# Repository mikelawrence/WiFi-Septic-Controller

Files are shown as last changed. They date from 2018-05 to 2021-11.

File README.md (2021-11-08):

# Wireless Septic Controller
I had some problems with my newly installed aerobic septic system when hurricane Harvey blew through. There was no significant flooding but there was plenty of rain and that seemed to cause the system to override pump multiple times. This board is designed to give visibility as to how often the pump runs and will detail alarm conditions. The effluent pump is controlled with an external 50A Solid-State-Relay (SSR). This board also provides an alarm output required by most aerobic septic systems. Normally the alarm switches are wired in parallel so that any alarm condition will turn on the light and audible alert. This board has separate inputs for three alarm switches so that the alarm condition can be identified. This board supports the following alarm types: air pressure failure alarm, tank high level alarm, and bleach low level alarm. WiFi is provided by an ATWINC1500 module which is an excellent low power WiFi module that is directly supported by Arduino. This board is fully compatible with the Arduino MRK1000 which includes a SAMD21G18 ARM processor and a ATWINC1500 module. This board uses MQTT to communicate with Home Assistant home automation software. The MQTT client/server model is very effective in this situation.

This PCB design uses my custom libraries available here [Mike's KiCad Libraries](https://github.com/mikelawrence/KiCad-Libraries).

This PCB was designed with [KiCad 5.1.2](http://kicad.org).

_Note: There is dangerous voltage present on this PCB. Use care when handling this board. Housing this board in a box is required to protect users from electrocution._

_Note: The LMZ21700 Simple Switcher, SAMD21G18 ARM Processor, and ATWINC1500 WiFi Module have exposed pads on the bottom which requires either a reflow oven or hot air to solder properly._

For Bill of Materials generation I use my version of [KiBoM](https://github.com/mikelawrence/KiBoM) forked from [SchrodingersGat](https://github.com/SchrodingersGat/KiBoM).

## Status
* Rev 1.1 PCB has been updated to support KiCad 5.1 libraries. Some footprints changed when libraries were updated but changes were minimal. This board has NOT been tested.
  * Order the PCB from [OSH Park](https://oshpark.com/shared_projects/a805S6zq).
  * Order the parts from Mouser using this [Shared BOM](https://www.mouser.com/ProjectManager/ProjectDetail.aspx?AccessID=a71ed4612f).
* Rev 1.0 PCB has been ordered, assembled, and tested. Hardware is fully operational.
  * Order the PCB from [OSH Park](https://oshpark.com/shared_projects/bguWSc9J).
  * Order the parts from Mouser using this [Shared BOM](https://www.mouser.com/ProjectManager/ProjectDetail.aspx?AccessID=a71ed4612f).

## Board Preview
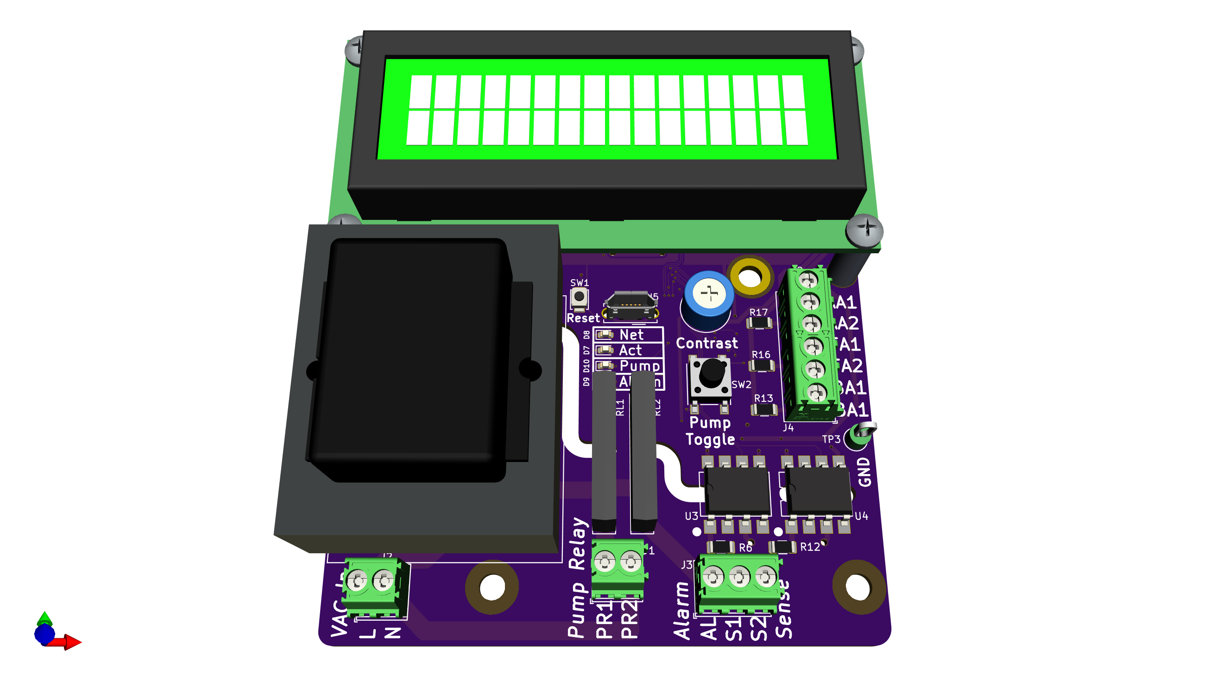
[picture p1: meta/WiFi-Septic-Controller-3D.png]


## Design
### Input Power
A transformer converts the 115VAC to 10VAC through a standard bridge rectifier and capacitor filter to arrive at approximately 12VDC. This voltage is fed to both a 3.3VDC and 5VDC Simpler Switcher from Texas Instruments (LMZ21700). The switchers can also be fed by the 5VDC from the USB connector when the 115VAC is not connected. But make note, the 5VDC is no longer regulated.

### Alarm Contact Inputs
There are three alarm contact inputs: air pressure failure alarm, tank high level alarm, and bleach low level alarm. Aerobic septic systems have an air compressor that pumps air into the septic tank, hence the name "aerobic". This air pump promotes bacterial growth and it runs all the time. If the air pump stops producing air pressure the air pressure failure alarm contact closes. Many aerobic septic systems use liquid bleach for the chlorine source and some regulatory boards require a low bleach level alarm. My aerobic septic system has three float switches but only one is the tank high level alarm. This float switch is at the highest point in the tank and this alarm means the pump cannot keep up with the water entering the tank. This is usually caused by the effluent pump failing.

In the previous wiring of the septic controller the alarm contacts were wired in parallel logically "or'ing" the alarms. The contacts switched 115VAC to the alarm light and audible alert. In order to determine the actual alarm state the wiring was changed to directly connect these contacts to the the board and they no longer switch 115VAC. The alarm contact inputs use a simple pullup to 5VDC and a Schmidt Trigger Inverter (SN74LVC2G14). Note: software debounce is still required. A high value pullup resistor and series resistor (both 100k) were selected to reduce current levels when accidental high voltages are applied to the input. ESD Protection devices are included to further protect the inputs. Due the inverted nature of the SN74LVC2G14 the software sees a logic high when the contact is closed.

### Sense Inputs
There are two 115VAC sense inputs (S1 and S2). These inputs are connected to an On Semiconductor MID400 AC Line Monitor. This optically-isolated device provides a logic low when 115VAC is present on the input. There is no flickering due to 60Hz AC. S1 is used to sense when the effluent pump has power. These is needed because the effluent pump can be turned on when the override float is tripped. S2 is currently unused.

### Relay Outputs
There are two relay outputs on the PR and ALM. Both are switched 115VAC by small board mount solid state relays  (). These SSRs provide overload protection for both temperature and current. The Pump Relay (PR) output is connected to the effluent pump 50A solid state relay (Crydom CWA2450-10). A 50A relay is needed to drive the 3/4hp effluent pump. Note this relay is controlled by 115VAC. The other relay output (AL) is the alarm output. The alarm light and audible alert require 10W at 115VAC. The alarm output is switched on when any alarm contact is closed. There is no software intervention required to produce an alarm.

### SAMD ARM Processor and WiFi Module
The ARM processor and ATWINC1500 WiFi module are wired identical to the MKR1000 Arduino board, thus the Arduino development environment is used for software development and the ATWINC1500 module is directly supported. Digital power is 3.3V and while the LCD is 5V there are no 5V outputs driving 3.3V inputs on the ARM processor so there is no problem wiring the LCD directly to the ARM processor. The LCD recognizes anything above 2.2VDC as a high so 3.3VDC logic outputs from ARM processor will be correctly interpreted by the LCD.

## Setup
### Arduino Setup
This board is designed to mimic a [MKR1000](https://store.arduino.cc/usa/arduino-mkr1000) board from Arduino. Make sure the the MKR1000 board is supported by installing Arduino SAMD Boards package. Do this by opening the Board Manager as shown below.

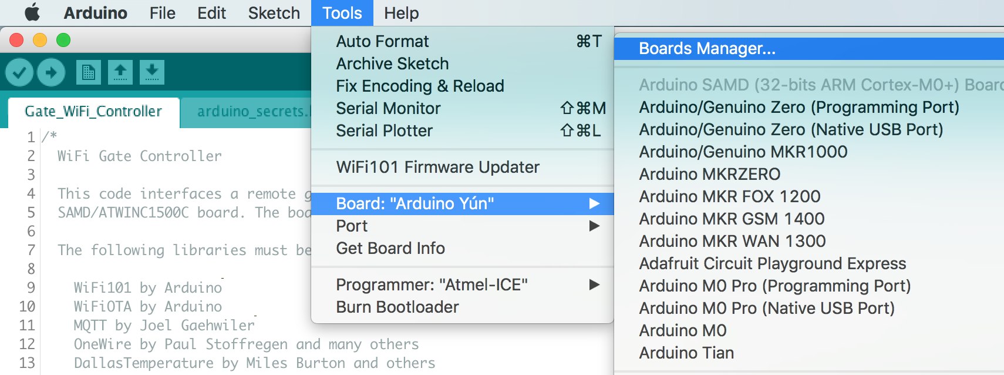
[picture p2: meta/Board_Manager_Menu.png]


Type in "samd" in the filter edit and you will see several options. Select "Arduino SAMD Boards (32-bits ARM Cortex-M0+)" and install the latest version as shown below.

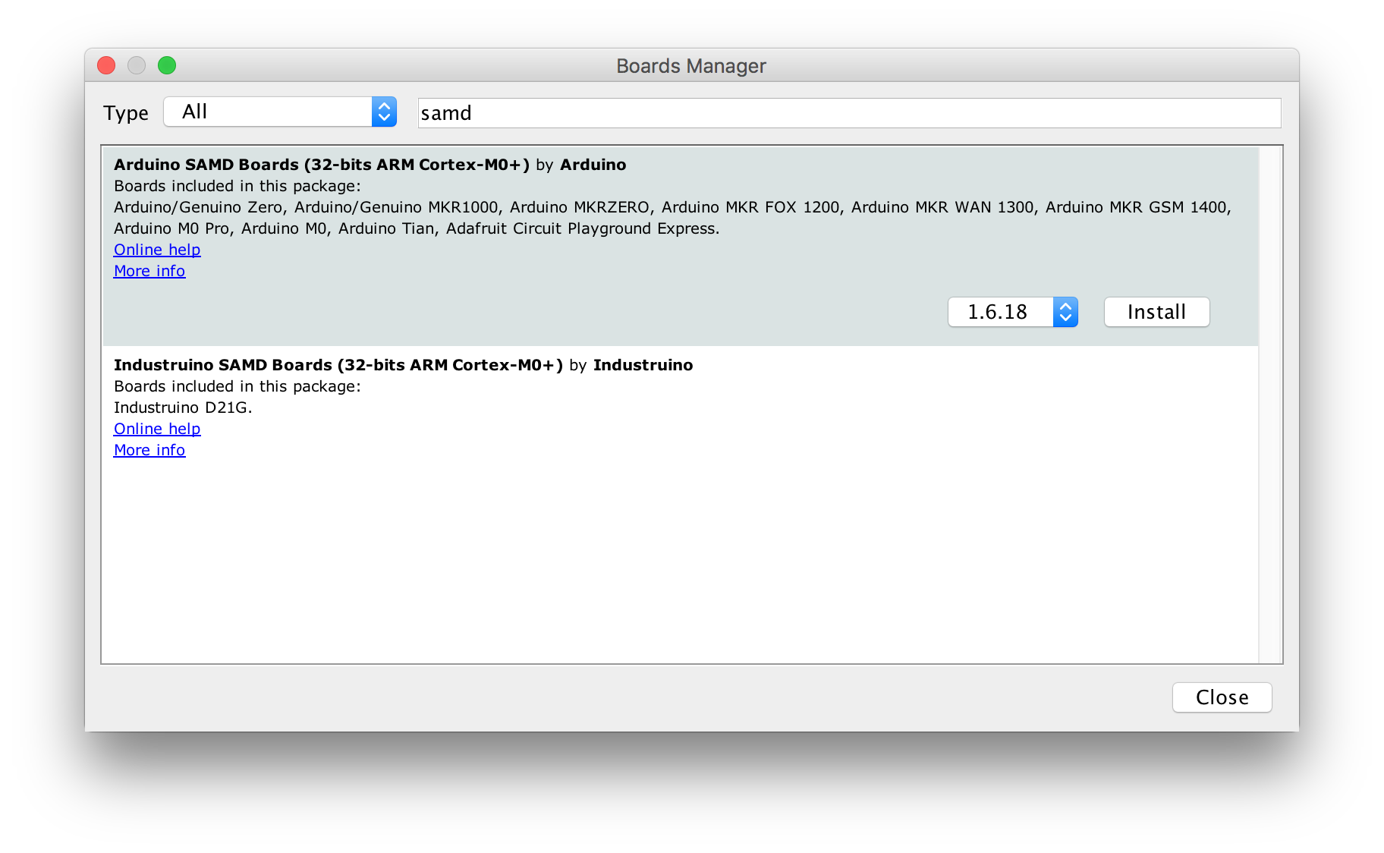
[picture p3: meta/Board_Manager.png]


It will take a few minutes to download and install the board package. Once complete it's time to install the necessary libraries. Start by opening the Library Manager as shown below.

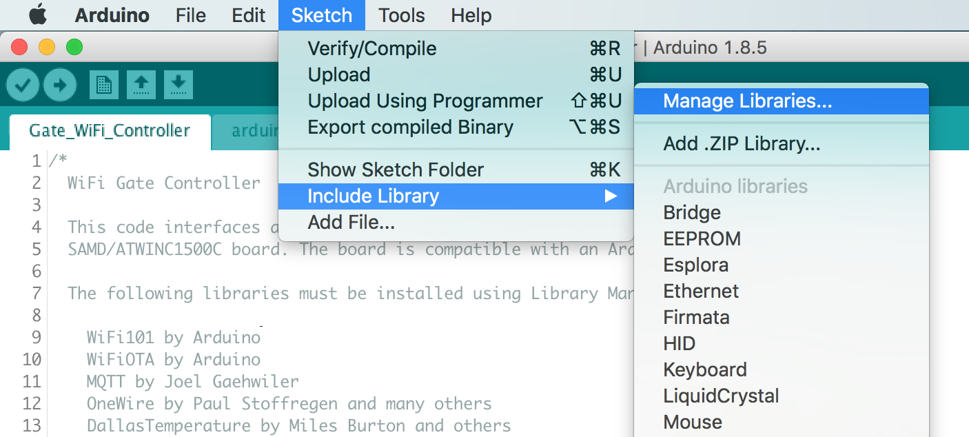
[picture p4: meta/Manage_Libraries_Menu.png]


Type in "mqtt" in the filter edit and scroll down until you see "MQTT by Joel Gaehwiler" as shown below.

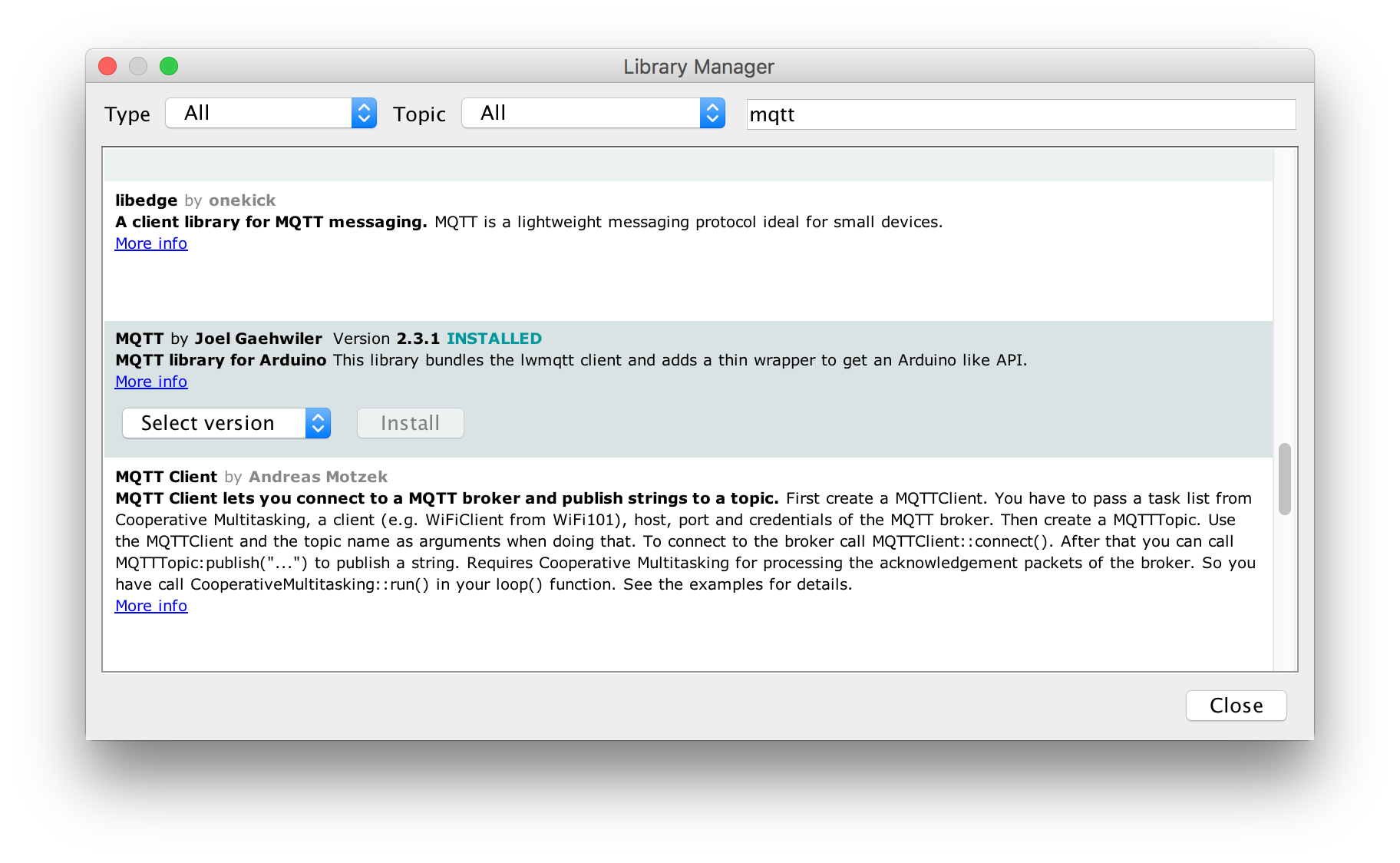
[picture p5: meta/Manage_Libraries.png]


Once "MQTT" is installed repeat the install for the following libraries.

* WiFi101 by Arduino
* WiFiOTA by Arduino
* OneWire by Paul Stoffregen and many others
* DallasTemperature by Miles Burton and others

### Board Setup
The Arduino development environment expects a bootloader in the SAMD ARM processor which will allow programming via USB. The bootloader must be programmed first using a supported programming pod. I used an "Atmel-ICE" pod but there are other options. First make sure you have selected the "Arduino/Genuino MKR1000" board as shown below.

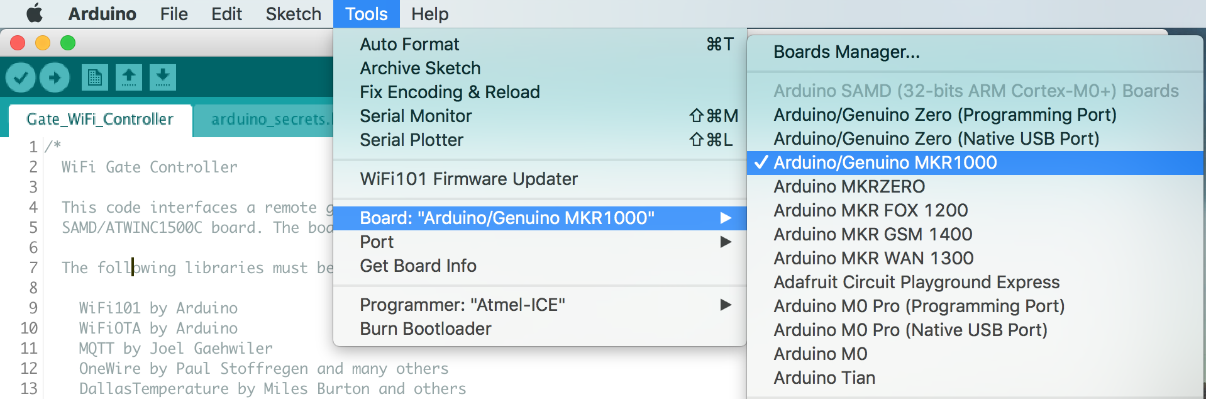
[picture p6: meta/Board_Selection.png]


Next select your programmer.

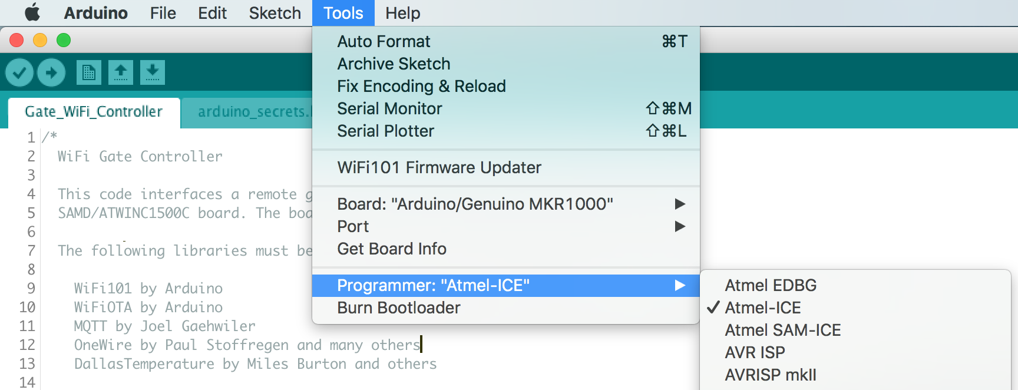
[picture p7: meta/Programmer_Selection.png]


Make sure the board is powered via USB and the programmer is connected to the debug connector then select "Burn Bootloader".

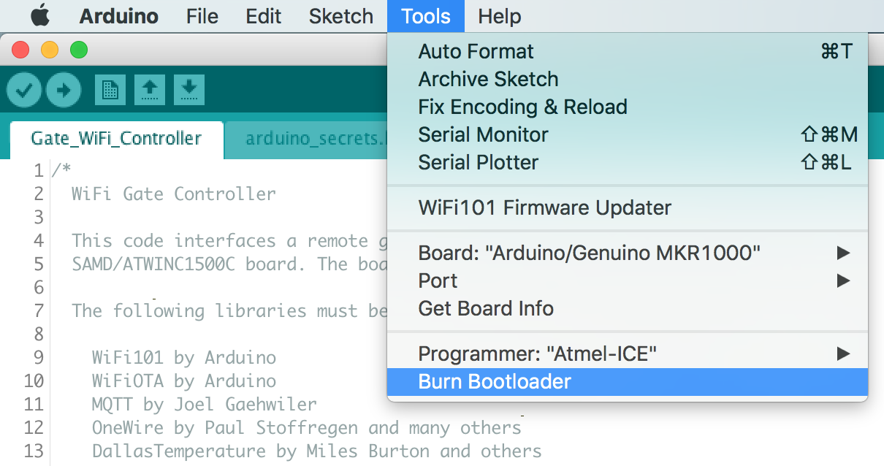
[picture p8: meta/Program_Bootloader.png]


Now the bootloader is programmed it's time to load the "WiFi101 FirmwareUpdater" example. This will update the firmware in the ATWINC1500 module.

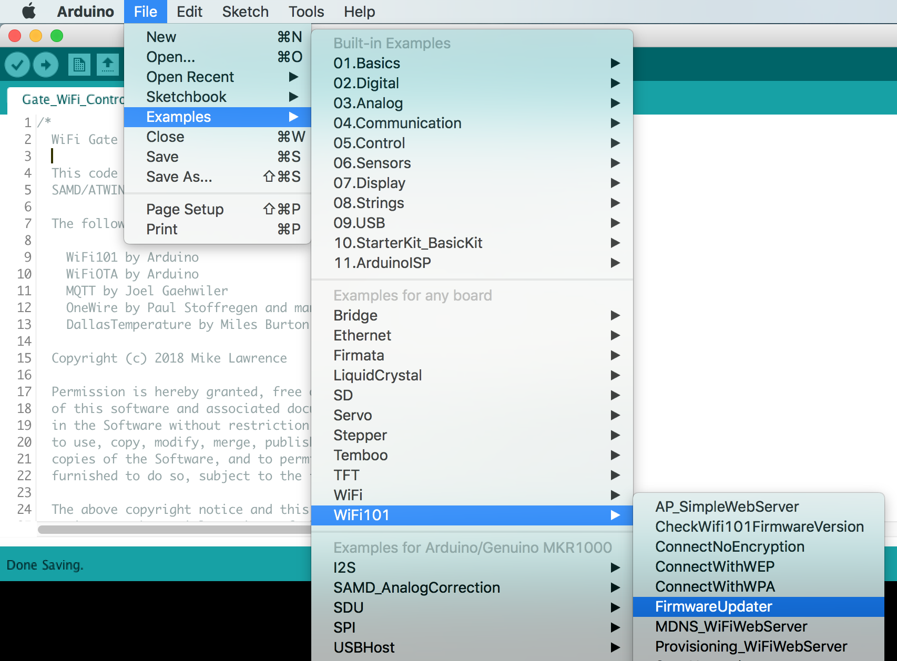
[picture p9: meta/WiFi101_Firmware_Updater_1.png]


Now "Upload" the "WiFi101 FirmwareUpdater" example.

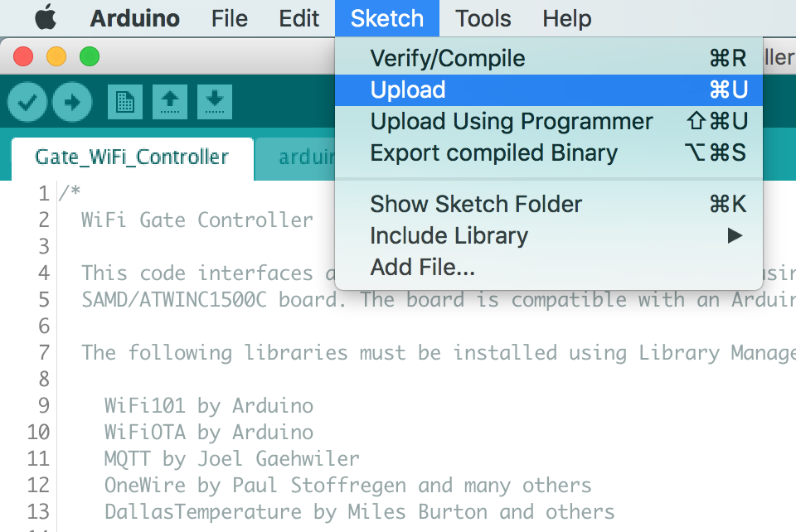
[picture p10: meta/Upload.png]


Update the ATWINC1500 module by selecting "WiFi101 Firmware Updater".

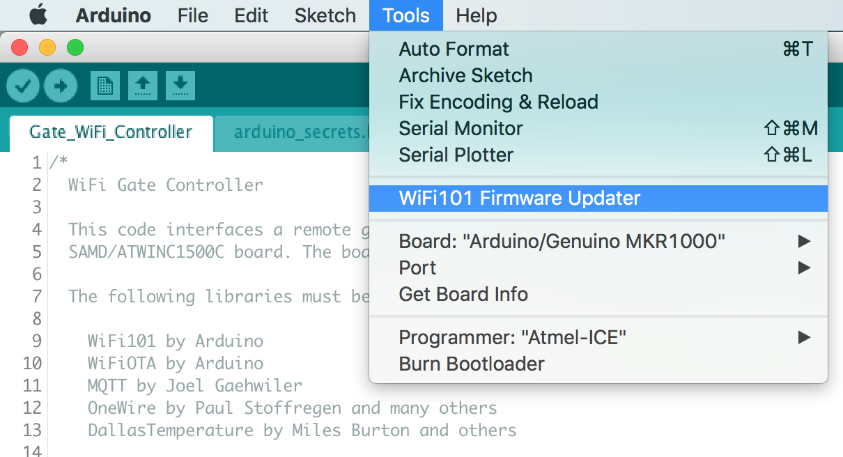
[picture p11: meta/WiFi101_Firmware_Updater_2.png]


Click the "Update Firmware" button.

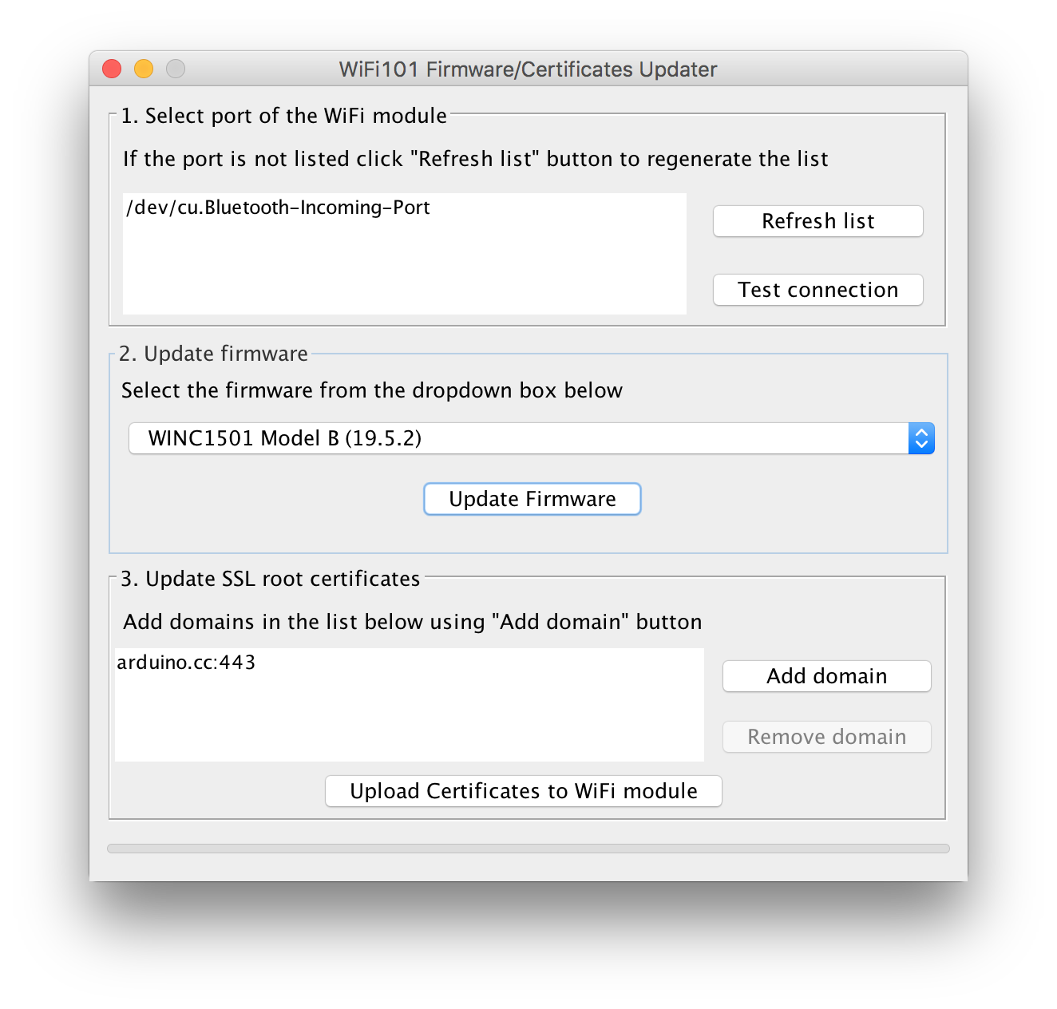
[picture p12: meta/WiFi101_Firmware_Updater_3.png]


Finally open the "Septic_WiFi_Controller.ino" sketch downloaded from GitHub. Update the necessary defines for your Wireless network and MQTT server settings see the [Code README](code/README.md) for more information. Now upload it just like the "WiFi101 FirmwareUpdater" example. All done!

# Acknowledgments
[Arduino](www.arduino.cc) kindly develops open source hardware and software which makes writing software for the board incredibly easy.

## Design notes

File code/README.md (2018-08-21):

# WiFi Septic Controller Sketch
The WiFi Septic Controller Sketch is written in C++. The sketch is primarily two state machines: one for effluent pump control and one for alarm state. The pump state machine can detect when the override float has applied power to the pump thus providing some indication of over usage or rain seepage into the tanks. The sketch is a discoverable set of sensors for [Home Assistant](https://home-assistant.io/), an open-source home automation platform running on Python. [MQTT](http://mqtt.org/), a machine-to-machine (M2M)/"Internet of Things" connectivity protocol, is the basis of communication with Home Assistant.

## Status
This software is in the testing stage and is connected to my septic system.
* This is now fixed. Automatic On at 1:00 AM is working but the time it comes has varied upwards of 15 minutes. Discovered that the WINC1500 module time keeping is pretty bad so it was bypassed with direct NTP handling in the WiFiRTC module.
* This is now fixed. Using WiFi Low Power mode may have contributed to the problem. Experienced the controller going silent on the network (pump state machine continues to work correctly). It appears that the WiFi module can loose connection and still show the status as connected. Added MQTT connect timeout which stops the WiFi connection. This stop causes the WiFi reconnect and hopefully fix the problem automatically. Also turned off WiFi Low Power Mode.
* Pump state machine is working nicely. Have tested Tank Empty, Off states, Manual On, Automatic On and Override On states. Overtemp state has not been tested.
* All alarms work correctly: Tank High Alarm, Air Pump Alarm, and Bleach Alarm. Overtemp Alarm has not been tested.
* Home Assistant detects all MQTT sensors: Status Sensor, Pump Sensor, Alarm Sensor, Temperature Sensor, and RSSI Sensor.

# Setup
## Sketch Setup
The arduino_secrets.h file is not included on Github. You must create and edit it to match your configuration.

```c
/******************************************************************
 * arduino_secrets.h
 ******************************************************************/
#define SECRET_SSID             "SSID of your WiFi network"
#define SECRET_PASSWORD         "Password for your WIFi network"
// IP address of MQTT server, host name should work but I've never tried
#define MQTT_SERVER             "192.168.0.230"
#define MQTT_SERVERPORT         1883
// MQTT user name and password leave as empty string if not used
#define MQTT_USERNAME           ""
#define MQTT_PASSWORD           ""
// Over-The-Air Update password if used
#define OTA_PASSWORD            "password"
```

The rest of the sketch settings are C defines in the [WiFi_Septic_Controller.h](WiFi Septic_Controller/WiFi_Septic_Controller.h) file. There are a few build defines that control how the sketch is built.

```c
/******************************************************************
 * Build defines
 ******************************************************************/
// Enable Watchdog Timer
#define ENABLE_WATCHDOG
// Enable OTA updates
#define ENABLE_OTA_UPDATES
// Enable Serial on USB
//#define ENABLE_SERIAL
// Enable Low Power Mode on WiFi
#define ENABLE_WIFI_LOW_POWER
// Current Version
#define VERSION                   "0.1"
```

* "ENABLE_WATCHDOG" - When defined, the Watchdog Timer is enabled with a 16 second timeout. This will reset the ARM processor is something goes bad.
* "ENABLE_OTA_UPDATES" - When defined, the sketch can be updated using Arduino's Over-The-Air Update capability.
* "ENABLE_SERIAL" - When defined, status information is sent out the serial connection which in this case is the USB port. Otherwise the serial port won't even be enabled.
* When "ENABLE_WIFI_LOW_POWER" is defined the WINC1500 module is set to Low Power Mode. This can drop the current requirements of the module to a third or even less. Low Power Mode reduces the transmit frequency to the beacon interval and may also cause the module to hang occasionally.

```c
/******************************************************************
 * Application defines
 ******************************************************************/
// Name of this board, each board should be unique
// Used as MQTT Client ID, HASS Name, and OTA Name
#define BOARD_NAME                "Septic"
// input debounce time in milliseconds
#define DEBOUNCE_TIME             100
// pump toggle switch input debounce time in milliseconds
//   Should be larger than DEBOUNCE_TIME
#define PUMP_TOGGLE_DEBOUNCE_TIME 500
// pump toggle switch input debounce time in milliseconds
//   Should be larger than DEBOUNCE_TIME
#define ALARM_DEBOUNCE_TIME       500
// pump state machine deadband time in milliseconds
#define PUMP_DEADBAND_TIME        2000
// alarm state machine deadband time in milliseconds
#define ALARM_DEADBAND_TIME       2000
// temperature publish time in milliseconds when pump is off
#define TEMP_PUBLISH_RATE         5 * 60 * 1000
// NTP server used to update local time, can be IP Address or name
#define NTP_SERVER                "time.nist.gov"
// timezone difference from GMT in hours (Standard Time difference)
#define TZDIFF                    -6
// Solid State Relay shutoff temperature in Celsius
#define SSR_SHUTOFF_TEMP          65.0

/******************************************************************
 * Home Assistant MQTT Defines
 ******************************************************************/
#define HASS_PREFIX               "hass"
#define HASS_NODE_NAME            "septic"
```
* "BOARD_NAME" - Names the board. It is used is several places including Home Assistant Name, OTA Name, and MQTT Client ID. This is a string.
* "DEBOUNCE_TIME" - How long to ignore sense changes on the input before accepting them as valid. This is an integer and the units are milliseconds.
* "PUMP_TOGGLE_DEBOUNCE_TIME" - How long to ignore contact changes on Pump Toggle switch. This is an integer and the units are milliseconds.
* "ALARM_DEBOUNCE_TIME" - How long to ignore contact changes on Alarm switch inputs. This is an integer and the units are milliseconds. Should be significantly larger than DEBOUNCE_TIME.
* "PUMP_DEADBAND_TIME" - How long after the Pump State Machine changes states before allowing another state change. This is an integer and the units are milliseconds.
* "ALARM_DEADBAND_TIME" - How long after the Alarm State Machine changes states before allowing another state change. This is an integer and the units are milliseconds.
* "TEMP_PUBLISH_RATE" - How often the temperature should be sampled and published via MQTT. This is an integer and the units are milliseconds. The time should not be less than 5000 milliseconds.
* "NTP_SERVER" - NTP Server that is used to update local time. NTP Updates occur slightly less than every 12 hours. This is a string and can be a valid DNS host name or IP Address.
* "TZDIFF" - Used to correct internet time for your given timezone. This should be the Standard Time timezone difference to GMT. It is a integer and units are hours.
* "SSR_SHUTOFF_TEMP" - Specifies the temperature is which the pump state machine will shut off the SSR. It is a float.
* "HASS_PREFIX" - The Home Assistant MQTT Discovery Prefix as defined in your system. This is a string.
* "HASS_NODE_NAME" - Used in the MQTT topics to identify the cover and sensor to Home Assistant. Home Assistant calls this the node id. It is a string and should not contain special characters including spaces.

## Home Assistant Setup
The sketch is setup to enable MQTT Discovery on Home Assistant. If you don't want to use discovery here is the configuration of the WiFi Septic Controller in Home Assistant. Note the 'Septic' in the name: definitions you see in the example yaml is the "BOARD_NAME" and 'septic' in topics is "HASS_NODE_NAME". The WiFi Septic Controller uses the [MQTT Sensor](https://home-assistant.io/components/sensor.mqtt/) and [MQTT Binary Sensor](https://www.home-assistant.io/components/binary_sensor.mqtt/) platforms.

```yaml
# Example configuration.yaml entry
sensor:
  # Septic Controller State
  - platform: mqtt
    name: "Septic Status"
    state_topic: "hass/sensor/septic/status/state"
  # Septic Controller Pump State
  - platform: mqtt
    name: "Septic Pump State"
    state_topic: "hass/binary_sensor/septic/pump/state"
  # Septic Controller Alarm State
  - platform: mqtt
    name: "Septic Alarm State"
    state_topic: "hass/binary_sensor/septic/alarm/state"
  # Septic Controller temperature
  - platform: mqtt
    name: "Septic Temperature"
    state_topic: "hass/sensor/septic/temperature/state"
    unit_of_measurement: "°C"
  # Septic Controller RSSI
  - platform: mqtt
    name: "Septic RSSI"
    state_topic: "hass/sensor/septic/rssi/state"
    unit_of_measurement: "dBm"
```

Septic Status can be one of the following:
* "Overtemp Alarm On" - The SSR temperature is too high and the effluent pump has been turned off. The pump will come back on when the temperature has dropped 15 C. Most likely the effluent pump is drawing too much current or the SSR is failing.
* "Tank High Alarm On" - The top float in the tank is on. Most likely the effluent pump is not working.
* "Air Pump Alarm On" - The air compressor is not producing any air pressure.
* "Bleach Alarm On" -  Bleach level is low.
* "Manual Pump On" - Effluent pump was manually turned on.
* "Auto Pump On" - Effluent pump was automatically turned on at 1:00AM.
* "Override Pump On" - The middle/override float is on which also turned on the effluent pump. This usually means too much water has entered the septic system.
* "Tank Empty" - This a short state that appears for a few seconds after pumping indicating the bottom float is off thus stopping any pumping state.
* "Idle" - Nothing to do except look pretty.

Once the board is running Home Assistant should automatically pick up the cover and sensors with MQTT Discovery. Debugging Home Assistant problems is a bit of a stretch for this guide but here are a couple of hints.

* Make sure you have MQTT installed. If you use HASS.IO goto the HASS.IO configuration and install the Mosquitto Broker.
* Make sure you have MQTT discovery enabled. See [MQTT Discovery](https://home-assistant.io/docs/mqtt/discovery/).
* Make sure your MQTT discovery prefix matches the HASS_PREFIX in the [WiFi_Septic_Controller.h](WiFi Septic_Controller/WiFi_Septic_Controller.h) file.

I use HASS.IO with the Mosquitto Broker add-on installed and my configuration for MQTT is as follows...

```yaml
mqtt:
  broker: core-mosquitto
  discovery: true
  discovery_prefix: hass

```

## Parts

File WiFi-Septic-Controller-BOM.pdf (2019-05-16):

Quantity | References | Description | Manufacturer | Part Number | Vendor | Vendor Part Number
2 | C1 C2 | CAP, SMD 10X10.5, 20%, EC, 50V | Panasonic | EEE-FT1H331GP | Mouser | 667-EEE-FT1H331GP
5 | C3 C5 C8 C10 C17 | CAP, 0805, 22uf, 20%, X5R, 25V | Taiyo Yuden | TMK212BBJ226MG-TT | Mouser | 963-TMK212BBJ226MGTT
2 | C4 C9 | CAP, 0603, 3300pF, 5%, X7R, 10V | Vishay | VJ0603Y332JXQPW1BC | Mouser | 77-VJ0603Y332JXQPBC
2 | C6 C7 | CAP, 0603, 1000pF, 10%, X7R, 10V | Vishay | VJ0603Y102KXAAC31 | Mouser | 77-VJ0603Y102KXAAC31
7 | C11 C12 C13 C14 C15 C21 C22 | CAP, 0603, 0.1uF, 20%, X7R, 10V | Vishay | VJ0603Y104JXQPW1BC | Mouser | 77-VJ0603Y104JXQPBC
2 | C16 C18 | CAP, 0603, 1uF, 20%, X7R, 10V | TDK | CGB3B1X7R1A105M055AC | Mouser | 810-CGB3B1X7R1A105MC
2 | C19 C20 | CAP, 0603, 15pF, 5%, C0G, 50V | AVX | 06035A150JAT2A | Mouser | 581-06035A150J
1 | D1 | DIO, PowerDI123, Schottky Rectifier, 30V, 1A | Diodes Inc | DFLS130LQ | Mouser | 621-DFLS130L
1 | D2 | DIO, DFS, Bridge Diode, 2A, 600V | Comchip Tech | DF206ST-G | Mouser | 750-DF206ST-G
3 | D3 D4 D5 | TVS, SOT23, ESD TVS Protection, Dual | Texas Instruments | TPD2E2U06QDBZRQ1 | Mouser | 595-TPD2E2U06QDBZRQ1
1 | D6 | TVS, SOT23, ESD Protection, USB | Nexperia | PRTR5V0U2X,215 | Mouser | 771-PRTR5V0U2X-T/R
1 | D7 | LED, 0603, Yellow LED | Lumex | SML-LX0603SYW-TR | Mouser | 696-SML-LX0603SYW
1 | D8 | LED, 0603, Green LED | Lumex | 696-SMLLX0603SGWTR | Mouser | 696-SML-LX0603SGW
1 | D9 | LED, 0603, Red LED | Lumex | SML-LX0603SRW-TR | Mouser | 696-SML-LX0603SRW
1 | D10 | LED, 0603, Blue LED | Lumex | SML-LX0603USBW-TR | Mouser | 696-SML-0603USBWTR
2 | J1 J2 | CON, THT, Terminal Block, 3.5mm, 2 Pos | Phoenix Contact | 1984617 | Mouser | 651-1984617
2 | J3 J8 | CON, THT, Terminal Block, 3.5mm, 3 Pos | Phoenix Contact | 1984620 | Mouser | 651-1984620
1 | J4 | CON, THT, Terminal Block, 3.5mm, 6 Pos | Phoenix Contact | 1984659 | Mouser | 651-1984659
1 | J5 | CON, THT, Micro USB 2.0 Type AB, Vertical | Wurth Electronics | 614105150721 | Mouser | 710-614105150621
1 | J6 | CON, THT, 2.54mm Socket, Single Row, Vertical, 18 Pos | Samtec | SSW-150-01-G-S | Digikey | SAM1209-50-ND
1 | | CON, THT, 2.54mm Header, Single Row, Vertical, 18 Pos | Samtec | TSW-150-14-G-S | Digikey | SAM1053-50-ND
1 | | MOD, LCD Negative 16X2, RGB Backlight | Unknown | GWT-C1627A-RGB | Adafruit | 399
1 | J7 | CON, SMD, 1.27mm Header, Dual Row, Vertical, 10 Pos | Amphenol FCI | 202112100010C4LF | Mouser | 649-202112100010C4LF
2 | L1 L2 | BEAD, 1206, 1k@100MHz, 2A | Murata | BLM31KN102SH1L | Mouser | 81-BLM31KN102SH1L
1 | L3 | BEAD, 0603, 470R@100MHz, 1A | Murata | BLM18PG471SN1D | Mouser | 81-BLM18PG471SN1D
7 | Q1 Q2 Q5 Q6 Q7 Q8 Q9 | TRANS, SOT23, Mosfet, P-CH, 115mA, 60V | On Semiconductor | 2N7002L | Mouser | 512-2N7002L
1 | Q3 | TRANS, SOT23, Mosfet, P-CH, -5A, -20V | Diodes Inc | DMG2305UX-7 | Mouser | 621-DMG2305UX-7
1 | Q4 | TRANS, SOT363, Bipolar, PNP, Dual Matched | Diodes Inc | BCM857BS-7-F | Mouser | 621-BCM857BS-7-F
1 | R1 | RES, 0603, 1.21M, 1%, T100 | Yageo | RC0603FR-071M21L | Mouser | 603-RC0603FR-071M21L
1 | R2 | RES, 0603, 383k, 1%, T100 | Panasonic | ERJ-3EKF3833V | Mouser | 667-ERJ-3EKF3833V
6 | R3 R5 R9 R11 R24 R26 | RES, 0603, 10k, 1%, T100 | Panasonic | ERJ-3EKF1002V | Mouser | 667-ERJ-3EKF1002V
1 | R4 | RES, 0603, 169R, 1%, T100 | Panasonic | ERJ-3EKF1690V | Mouser | 667-ERJ-3EKF1690V
8 | R6 R12 R13 R14 R15 R16 R17 R18 | RES, 1206, 22k, 5%, T200 | Panasonic | ERJ-P08J223V | Mouser | 667-ERJ-P08J223V
1 | R7 | RES, 0603, 232k, 1%, T100 | Yageo | RC0603FR-07232KL | Mouser | 603-RC0603FR-07232KL
1 | R8 | RES, 0603, 44.2k, 1%, T100 | Panasonic | ERJ-3EKF4422V | Mouser | 667-ERJ-3EKF4422V
1 | R10 | RES, 0603, 47k, 1%, T100 | Panasonic | ERJ-3EKF4702V | Mouser | 667-ERJ-3EKF4702V
3 | R19 R20 R21 | RES, 0603, 130R, 1%, T100 | Panasonic | ERJ-3EKF1300V | Mouser | 667-ERJ-3EKF1300V
1 | R22 | RES, 0603, 4.7k, 1%, T100 | Panasonic | ERJ-3EKF4701V | Mouser | 667-ERJ-3EKF4701V
1 | R23 | RES, 0603, 39R, 1%, T100 | Panasonic | ERJ-3EKF39R0V | Mouser | 667-ERJ-3EKF39R0V
1 | R25 | RES, 0603, 330R, 1%, T100 | Panasonic | ERJ-3EKF3300V | Mouser | 667-ERJ-3EKF3300V
2 | R28 R29 | RES, 0603, 698R, 1%, T100 | Panasonic | ERJ-3EKF6980V | Mouser | 667-ERJ-3EKF6980V
2 | RL1 RL2 | RLY, THT, Solid State, Form A, Protected, 230V, 450mA | IXYS | CPC1511Y | Mouser | 849-CPC1511
1 | RV1 | POT, THT, 10k, Round | Bourns | 3339P-1-103LF | Mouser | 652-3339P-1-103LF
1 | SW1 | SW, SMD, Push Button | Omron | B3U-1000P | Mouser | 653-B3U-1000P
1 | SW2 | SW, SMD, Push Button | Panasonic | PTS645SK70SMTR92LFS | Mouser | 611-PTS645SM13SMTR92
1 | T1 | XFMR, THT, 120/240V to 8/16V, 310mA | Triad Magnetics | VPP16-310 | Mouser | 553-VPP16-310
2 | U1 U2 | MODULE, SMD, Simple Switcher, 17V, .65A | TI | LMZ21700SILR | Mouser | 595-LMZ21700SILR
2 | U3 U4 | IC, SMDIP8, Optical AC Line Monitor | On Semi | MID400S | Mouser | 512-MID400S
2 | U5 U7 | IC, SOT23-6, Dual inverting Schmitt trigger | Texas Instruments | SN74LVC2G14DBVG4 | Mouser | 595-SN74LVC2G14DBVG4
1 | U6 | MODULE, SMD, WiFi, u.FL connector | Atmel | ATWINC1500-MR210UB1140 | Mouser | 579-C1500MR210UB1140
1 | U8 | IC, QFN44, MCU, ARM, 256kB Flash, 32kB SRAM, 48MHz | Atmel | ATSAMD21G18A-MUT | Mouser | 556-ATSAMD21G18A-MUT
1 | Y1 | XTL, SMD, 32.768kHz | Abracon | ABS07-32.768KHZ-9-T | Mouser | 815-ABS07-32.768K9T

# WiFi Septic Controller Rev 1.1

1

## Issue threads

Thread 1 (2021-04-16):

Updated Parts List

FracKenA, 2021-04-16:
Is it possible for you to review the parts list at mouser for the 1.1 version of the board? There are several parts I am wondering if you know of a direct substitution for the backordered items, some of the lead times are almost a year.

mikelawrence, 2021-04-16:
ABS07-32.768KHZ-9-T can be replaced by ABS07AIG-32.768KHZ-9-D-T
ATSAMD21G18A-MUT can be replaced by ATSAMD21G18A-MF
For the R's, L's, and C's you just need to determine the package size, value, voltage, power and cross to something equivalent. These small component shortages have been plaguing the industry for a while now.

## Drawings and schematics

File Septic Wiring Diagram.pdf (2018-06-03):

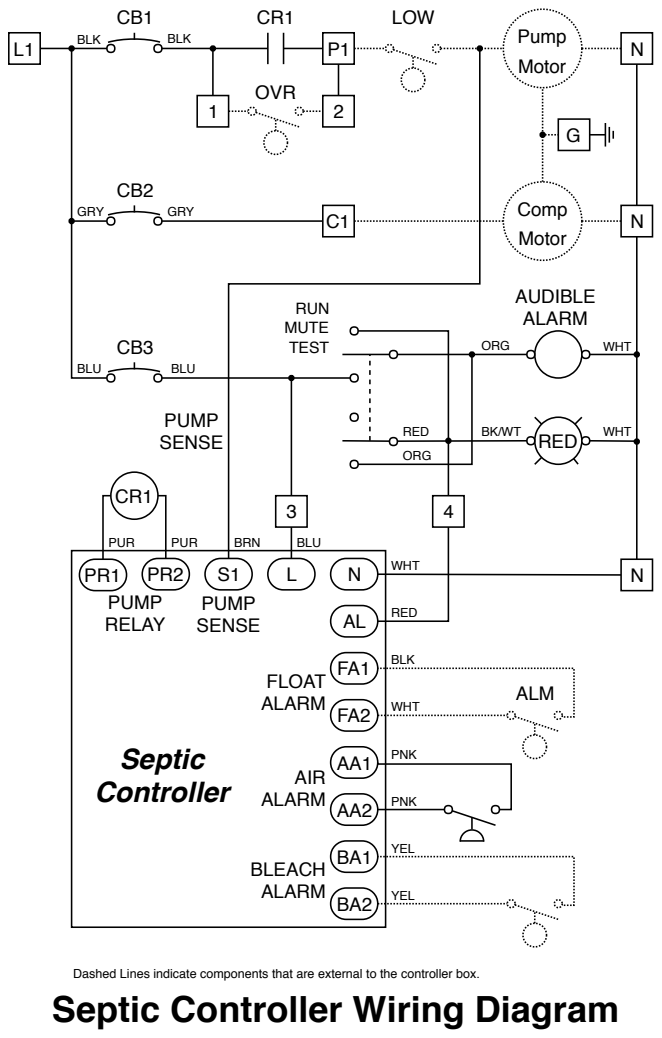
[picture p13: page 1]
OVR; MUTE; RUN; RED; AUDIBLE ALARM; PNK; BLU; WHT; PUMP SENSE; Septic Controller; Pump; Motor; Comp; LOW; BLK; GRY; ORG; TEST; ALM; BRN; YEL; PUR; PUMP RELAY; FLOAT ALARM; AIR ALARM; BLEACH ALARM

Dashed Lines indicate components that are external to the controller box.
Septic Controller Wiring Diagram

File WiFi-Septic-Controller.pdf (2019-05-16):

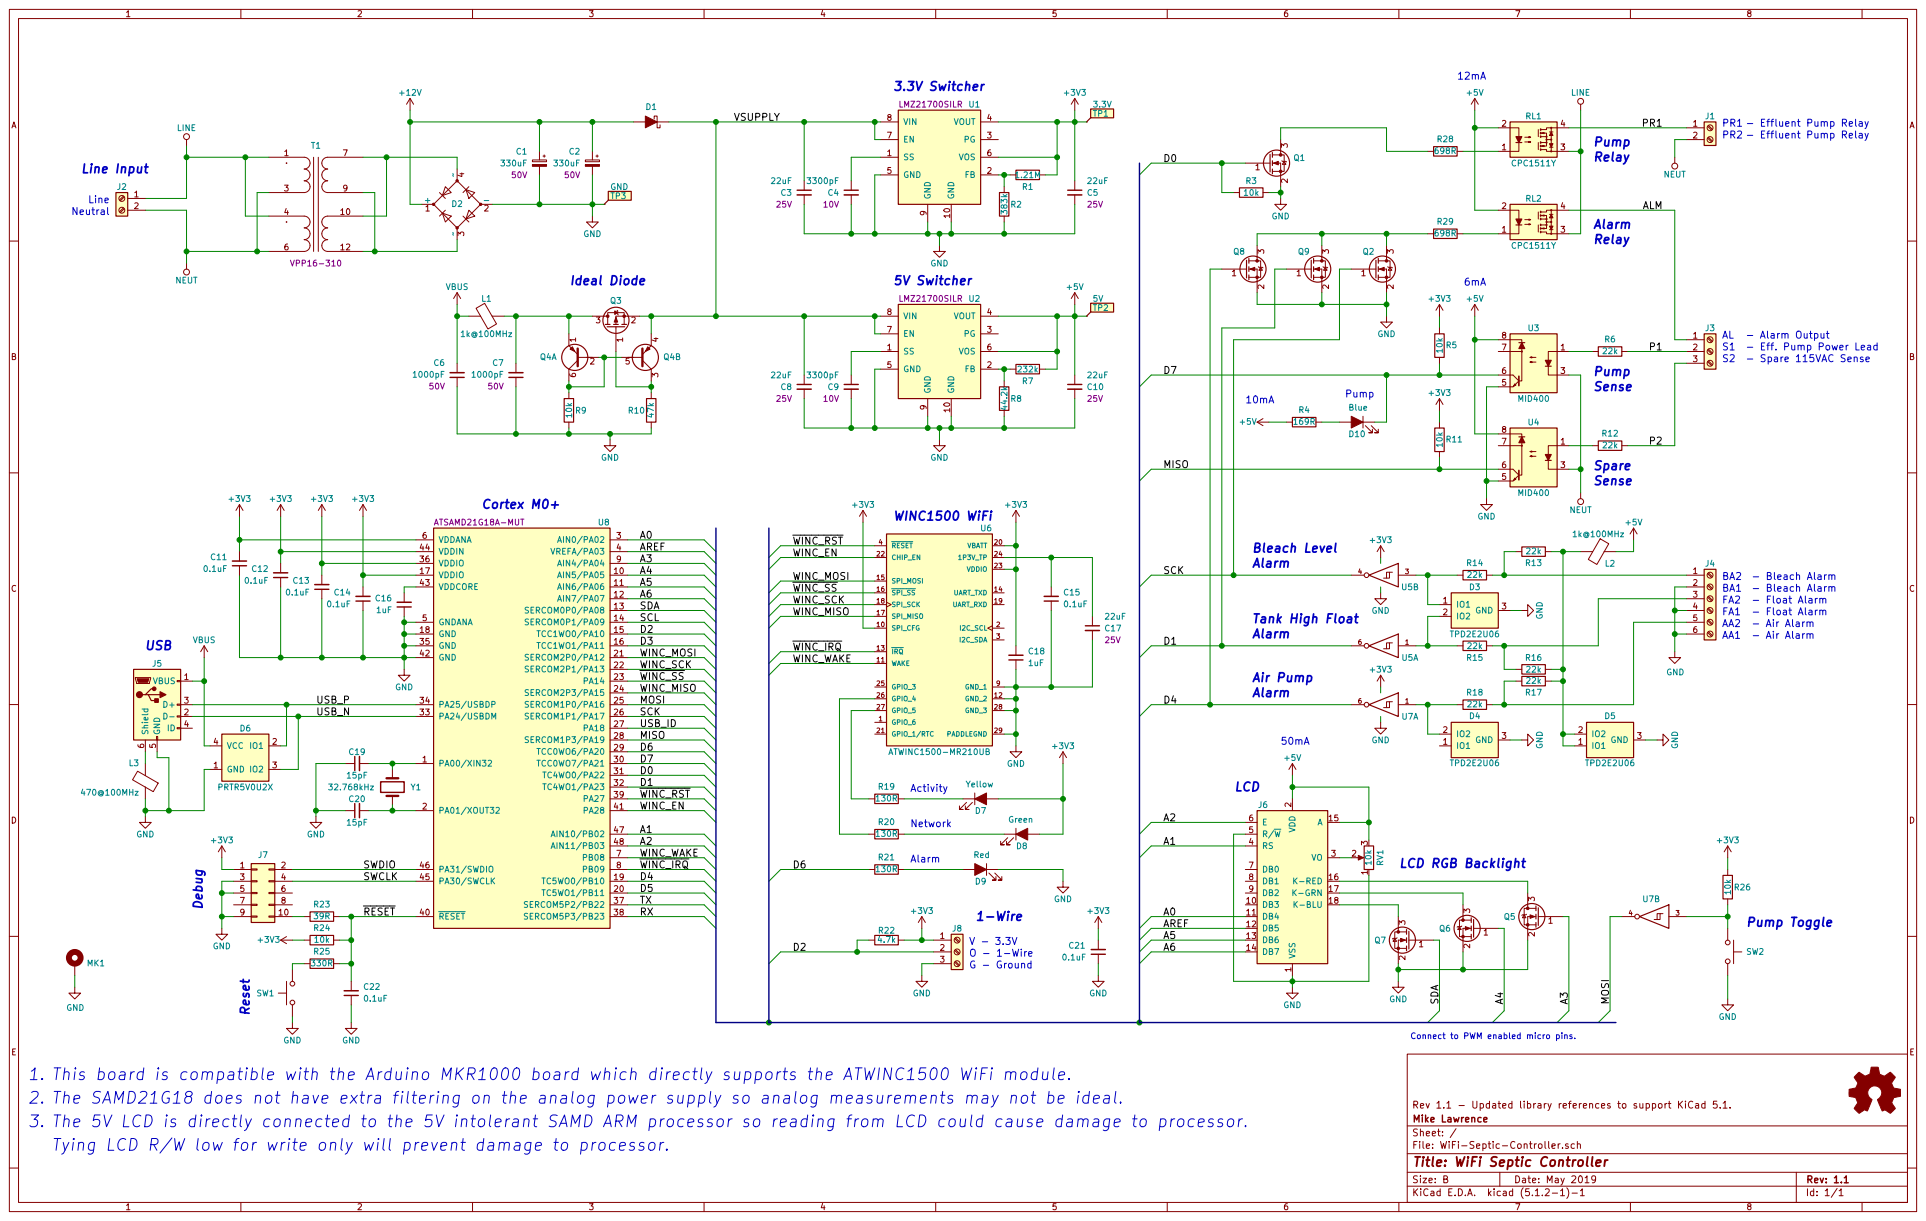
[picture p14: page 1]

2 Q2 3 GND 3.3V Switcher SS 1 GND 10 FB 2 PG 3 VOUT 4 GND 5 VOS 6 EN 7 VIN 8 GND

10k Tying LCD R/W low for write only will prevent damage to processor.

- Eff. Pump Power Lead
S2 - Spare 115VAC Sense

SWCLK

7 9 | 8

4.7k 1. This board is compatible with the Arduino MKR1000 board which directly supports the ATWINC1500 WiFi module.

Connect to PWM enabled micro pins. Reset

File: WiFi-Septic-Controller.sch Sheet: / Mike Lawrence Rev 1.1 - Updated library references to support KiCad 5.1. GND

Id: 1/1 Title: WiFi Septic Controller

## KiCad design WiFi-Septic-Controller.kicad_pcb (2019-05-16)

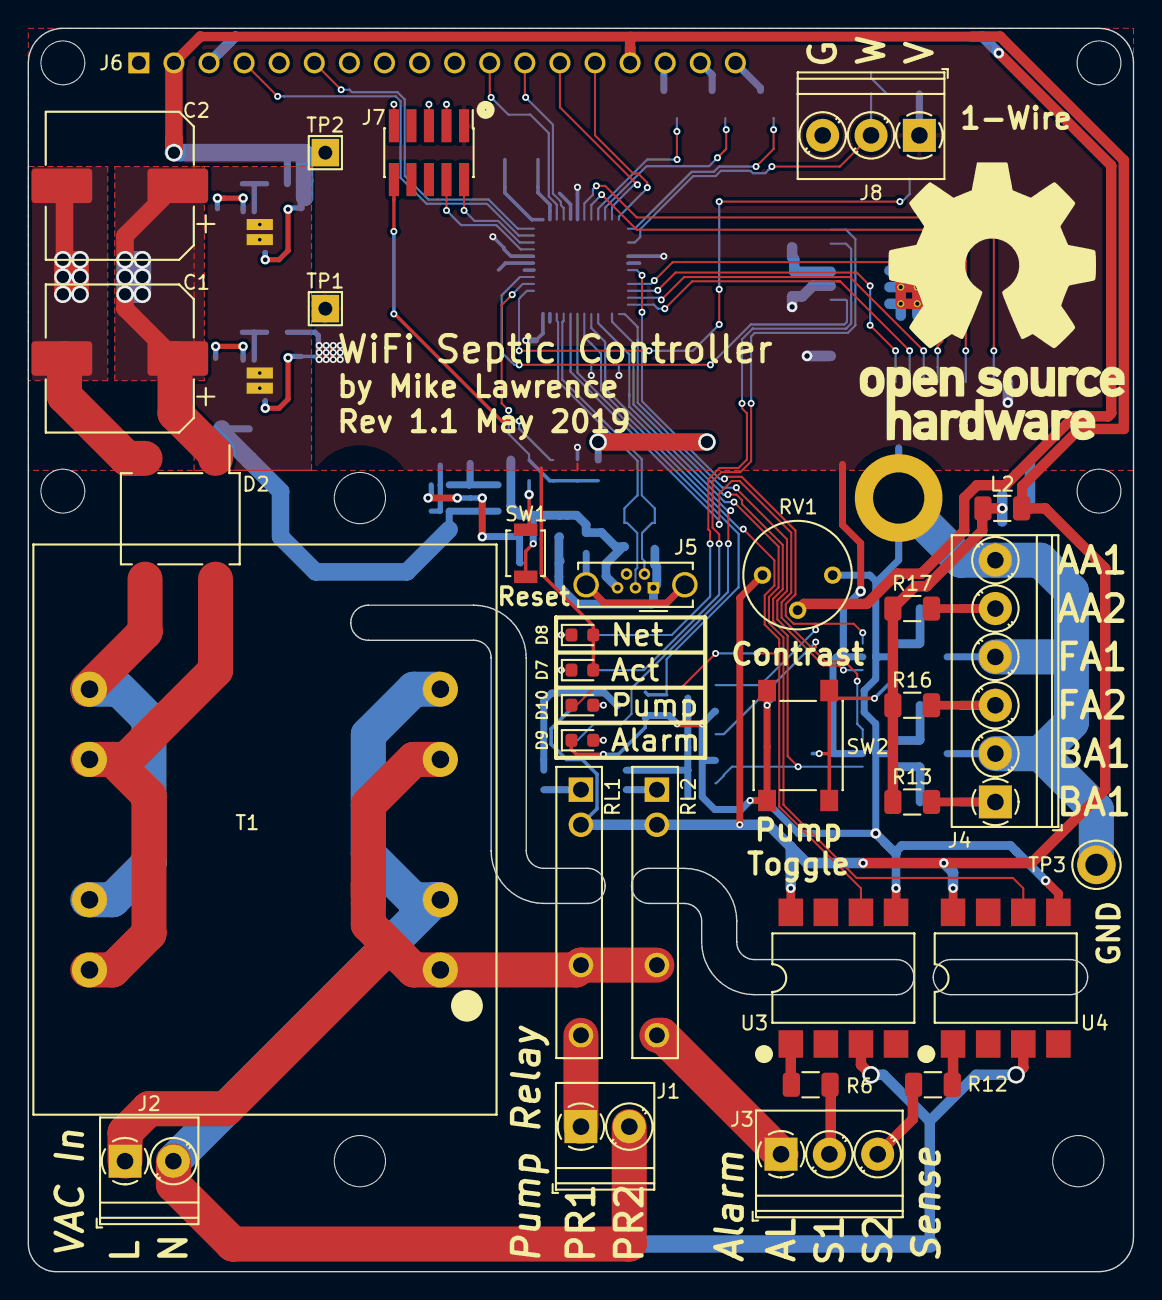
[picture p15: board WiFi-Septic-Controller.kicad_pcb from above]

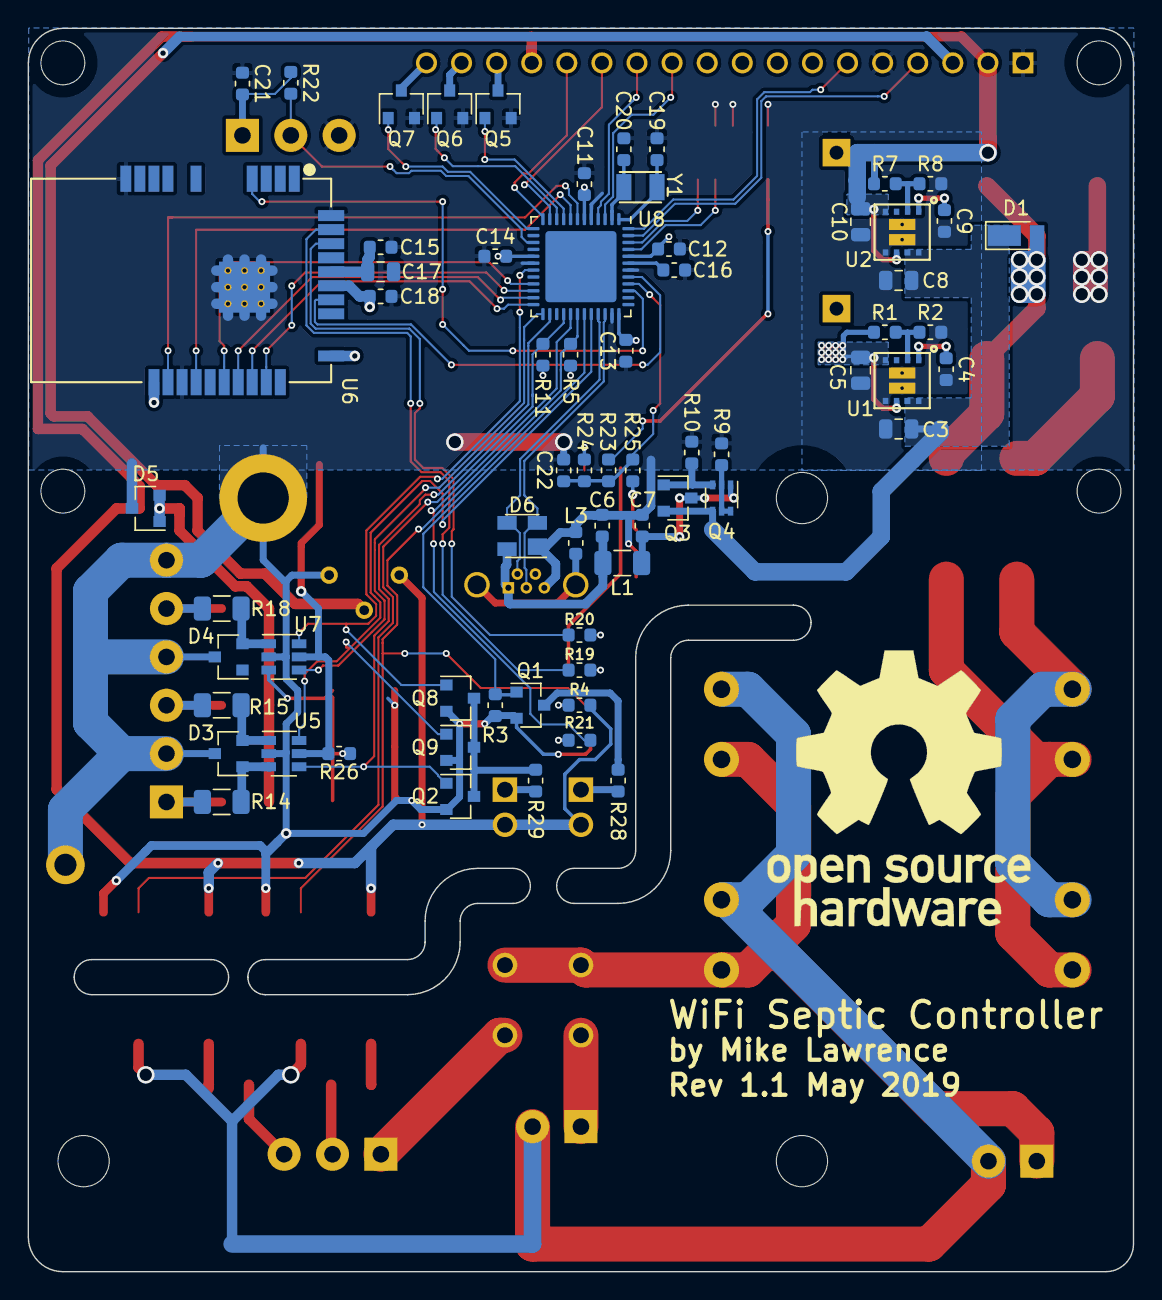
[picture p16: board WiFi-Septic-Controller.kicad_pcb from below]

Board: 2 copper layers, 80.0 x 90.0 mm, 102 parts (66 on the bottom side), 83 nets.

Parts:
C1, C2: 330uF; CP_Elec_10x10.5
C3, C5, C8, C10, C17: 22uF; C_0805_2012Metric
C4, C9: 3300pF; C_0603_1608Metric
C6, C7: 1000pF; C_0603_1608Metric
C11, C12, C13, C14, C15, C21, C22: 0.1uF; C_0603_1608Metric
C16, C18: 1uF; C_0603_1608Metric
C19, C20: 15pF; C_0603_1608Metric
D1: DFLS130; D_PowerDI-123
D2: D_Bridge_+-AA; Diode_Bridge_Vishay_DFS
D3, D4, D5: TPD2E2U06; SOT-23
D6: PRTR5V0U2X; SOT-143
D7: Yellow; LED_0603_1608Metric
D8: Green; LED_0603_1608Metric
D9: Red; LED_0603_1608Metric
D10: Blue; LED_0603_1608Metric
J1, J2: Screw_Terminal_01x02; TerminalBlock_Phoenix_PT-1,5-2-3.5-H_1x02_P3.50mm_Horizontal
J3, J8: Screw_Terminal_01x03; TerminalBlock_Phoenix_PT-1,5-3-3.5-H_1x03_P3.50mm_Horizontal
J4: Screw_Terminal_01x06; TerminalBlock_Phoenix_PT-1,5-6-3.5-H_1x06_P3.50mm_Horizontal
J5: USB_B_Micro; USB_Micro-B_Wuerth_614105150721_Vertical_CircularHoles
J6: GWT-C1627A-RGB
J7: Cortex Debug; PinHeader_2x05_P1.27mm_Vertical_SMD
L1, L2: 1k@100MHz; L_1206_3216Metric
L3: 470@100MHz; L_0603_1608Metric
MK1: Mounting_Hole_PAD; 6-32_PTH_Mounting_Hole
MK2, MK3, MK4: 6-32_NPTH_Mounting_Hole
Q1, Q2, Q5, Q6, Q7, Q8, Q9: 2N7002; SOT-23
Q3: DMG2305UX; SOT-23
Q4: BCM857BS; SOT-363_SC-70-6
R1: 1.21M; R_0603_1608Metric
R2: 383k; R_0603_1608Metric
R3, R5, R9, R11, R24, R26: 10k; R_0603_1608Metric
R4: 169R; R_0603_1608Metric
R6, R12, R13, R14, R15, R16, R17, R18: 22k; R_1206_3216Metric
R7: 232k; R_0603_1608Metric
R8: 44.2k; R_0603_1608Metric
R10: 47k; R_0603_1608Metric
R19, R20, R21: 130R; R_0603_1608Metric
R22: 4.7k; R_0603_1608Metric
R23: 39R; R_0603_1608Metric
R25: 330R; R_0603_1608Metric
R28, R29: 698R; R_0603_1608Metric
RL1, RL2: CPC1511Y; Relay_IXYS_PowerSIP
RV1: 10k; Potentiometer_Bourns_3339P_Vertical
SW1: Reset; SW_SPST_B3U-1000P
SW2: Pump; SW_SPST_PTS645
T1: VPP-XFMR; Triad_VPP_5.0VA
TP1: 3.3V; TestPoint_THTPad_2.0x2.0mm_Drill1.0mm
TP2: 5V; TestPoint_THTPad_2.0x2.0mm_Drill1.0mm
TP3: GND; TestPoint_Keystone_5010-5014_Multipurpose
U1, U2: LMZ21700; Converter_DCDC_Texas-SIL0008E
U3, U4: MID400; SMDIP-8_W9.53mm
U5, U7: 74LVC2G14; SOT-23-6
U6: ATWINC1500-MR210UB; Microchip_ATWINC1500-MR210UB
U8: SAMD21G18-M; QFN-48-1EP_7x7mm_P0.5mm_EP5.15x5.15mm
Y1: 32.768kHz; Crystal_SMD_Abracon_ABS07-2Pin_3.2x1.5mm

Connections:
+3V3: C5.1, C11.2, C12.2, C13.2, C14.2, C18.2, C21.2, D7.2, D8.2, J7.1, J8.1, R1.1, R5.2, R11.2, R22.1, R24.2, R26.1, TP1.1, U1.4, U1.6, U5.5, U6.10, U6.20, U6.23, U7.5, U8.6, U8.17, U8.36, U8.44
+5V: C10.1, J6.2, J6.15, L2.1, R4.2, R7.1, RL1.2, RL2.2, RV1.3, TP2.1, U2.4, U2.6, U3.8, U4.8
+12V: C1.1, C2.1, D1.2, D2.1
/A0: J6.11, U8.3
/A1: J6.4, U8.47
/A2: J6.6, U8.48
/A3: Q5.1, U8.9
/A4: Q6.1, U8.10
/A5: J6.13, U8.11
/A6: J6.14, U8.12
/ALM: J3.1, RL2.4
/AREF: J6.12, U8.4
/D0: Q1.1, R3.1, U8.31
/D1: Q9.1, U5.6, U8.32
/D2: J8.2, R22.2, U8.15
/D4: Q8.1, U7.6, U8.19
/D6: R21.1, U8.29
/D7: D10.1, R5.1, U3.6, U8.30
/MISO: R11.1, U4.6, U8.28
/MOSI: U7.4, U8.25
/P1: J3.2, R6.1
/P2: J3.3, R12.1
/PR1: J1.1, RL1.4
/SCK: Q2.1, U5.4, U8.26
/SDA: Q7.1, U8.13
/SWCLK: J7.4, U8.45
/SWDIO: J7.2, U8.46
/USB_N: D6.3, J5.2, U8.33
/USB_P: D6.2, J5.3, U8.34
/VSUPPLY: C3.1, C8.1, D1.1, Q3.2, Q4.4, U1.7, U1.8, U2.7, U2.8
/WINC_EN: U6.22, U8.41
/WINC_MISO: U6.17, U8.24
/WINC_MOSI: U6.15, U8.21
/WINC_SCK: U6.18, U8.22
/WINC_WAKE: U6.11, U8.7
/~RESET~: C22.2, R23.1, R24.1, R25.1, U8.40
/~WINC_IRQ: U6.13, U8.8
/~WINC_RST: U6.4, U8.39
/~WINC_SS: U6.16, U8.23
GND: C1.2, C2.2, C3.2, C4.2, C5.2, C6.1, C7.1, C8.2, C9.2, C10.2, C11.1, C12.1, C13.1, C14.1, C15.1, C16.1, C17.2, C18.1, C19.1, C20.1, C21.1, C22.1, D2.2, D3.3, D4.3, D5.3, D6.1, D9.1, J4.2, J4.4, J4.6, J5.5, J6.1, J6.5, J7.3, J7.5, J7.9, J8.3, L3.1, MK1.1, Q1.2, Q2.2, Q5.2, Q6.2, Q7.2, Q8.2, Q9.2, R2.2, R3.2, R8.2, R9.2, R10.2, RV1.1, SW1.2, SW2.2, TP3.1, U1.5, U1.9, U1.10, U2.5, U2.9, U2.10, U3.5, U4.5, U5.2, U6.9, U6.12, U6.28, U6.29, U7.2, U8.5, U8.18, U8.35, U8.42
LINE: J2.1, RL1.3, RL2.3, T1.1, T1.4
NEUT: J1.2, J2.2, T1.3, T1.6, U3.3, U4.3
unnamed: C4.1, U1.1
unnamed: C7.2, L1.2, Q3.3, Q4.1
unnamed: C9.1, U2.1
unnamed: C15.2, C17.1, U6.24
unnamed: C16.2, U8.43
unnamed: C19.2, U8.1, Y1.1
unnamed: C20.2, U8.2, Y1.2
unnamed: D2.3, T1.9, T1.12
unnamed: D2.4, T1.7, T1.10
unnamed: D3.1, R14.2, U5.3
unnamed: D3.2, R15.2, U5.1
unnamed: D4.2, R18.2, U7.1
unnamed: D5.1, D5.2, L2.2, R13.1, R16.1, R17.1
unnamed: D7.1, R19.2
unnamed: D8.1, R20.2
unnamed: D9.2, R21.2
unnamed: D10.2, R4.1
unnamed: J4.1, R13.2, R14.1
unnamed: J4.3, R15.1, R16.2
unnamed: J4.5, R17.2, R18.1
unnamed: J5.6, L3.2
unnamed: J6.3, RV1.2
unnamed: J6.16, Q5.3
unnamed: J6.17, Q6.3
unnamed: J6.18, Q7.3
unnamed: J7.10, R23.2
unnamed: Q1.3, R28.1
unnamed: Q2.3, Q8.3, Q9.3, R29.1
unnamed: Q3.1, Q4.3, R10.1
unnamed: Q4.2, Q4.5, Q4.6, R9.1
unnamed: R1.2, R2.1, U1.2
unnamed: R6.2, U3.1
unnamed: R7.2, R8.1, U2.2
unnamed: R12.2, U4.1
unnamed: R19.1, U6.27
unnamed: R20.1, U6.26
unnamed: R25.2, SW1.1
unnamed: R26.2, SW2.1, U7.3
unnamed: R28.2, RL1.1
unnamed: R29.2, RL2.1
VBUS: C6.2, D6.4, J5.1, L1.1

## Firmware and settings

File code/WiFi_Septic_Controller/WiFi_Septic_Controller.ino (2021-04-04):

/*
  WiFi Septic Controller 
  
  This code acts as an Aerobic Septic Controller using a custom 
  SAMD/ATWINC1500C board. The board is compatible with an Arduino MKR1000.
  The sketch is primarily two state machines: one for effluent pump control
  and one for alarm state. The pump state machine can detect when the 
  override float has applied power to the pump thus providing some indication 
  of over usage or rain seepage into the tanks. The sketch is a discoverable 
  set of sensors for Home Assistant, an open-source home automation platform 
  running on Python.
  
  MQTT, a machine-to-machine (M2M)/"Internet of Things" connectivity 
  protocol, is the basis of communication with Home Assistant.
  
  Built with Arduino IDE 1.8.14 Hourly Build
  
  The following libraries must be installed using Library Manager:
  
    WiFi101 version 0.16.1 by Arduino
      WINC1501 Model B firmware version 19.6.1
    WiFi101OTA version 1.0.2 by Arduino
    LiquidCrystal version 1.0.7 by Arduino
    MQTT version 2.5.0 by Joel Gaehwiler
    OneWire version 2.3.5 by Paul Stoffregen and many others
    DallasTemperature version 3.9.0 by Miles Burton and others
  
  Copyright (c) 2021 Mike Lawrence
  
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
  THE SOFTWARE IS PROVIDED "AS IS", WITHOUT WARRANTY OF ANY KIND, EXPRESS OR
  IMPLIED, INCLUDING BUT NOT LIMITED TO THE WARRANTIES OF MERCHANTABILITY,
  FITNESS FOR A PARTICULAR PURPOSE AND NONINFRINGEMENT. IN NO EVENT SHALL THE
  AUTHORS OR COPYRIGHT HOLDERS BE LIABLE FOR ANY CLAIM, DAMAGES OR OTHER
  LIABILITY, WHETHER IN AN ACTION OF CONTRACT, TORT OR OTHERWISE, ARISING FROM,
  OUT OF OR IN CONNECTION WITH THE SOFTWARE OR THE USE OR OTHER DEALINGS IN THE
  SOFTWARE.
*/
// Modify ../WiFi101/src/bsp/include/nm_bsp_internal.h library file
// so that CONF_PERIPH is defined. This will enabled LEDS from WiFi Module
#include <WiFi101.h>
#include <WiFi101OTA.h>
#include <MQTT.h>
#include <avr/dtostrf.h>
#include "WiFi_Septic_Controller.h"
#include "SepticLCD.h"
#include "WiFiRTC.h"
#include "arduino_secrets.h"

/******************************************************************
 * Definitions in arduino_secrets.h
 ******************************************************************/
/*
#define SECRET_SSID             "SSID of your WiFi network"
#define SECRET_PASSWORD         "Password for your WIFi network"
// IP address of MQTT server, host name may work but I've never tried
#define MQTT_SERVER             "192.168.0.230"
#define MQTT_SERVERPORT         1883
// MQTT user name and password leave as empty string if not used
#define MQTT_USERNAME           ""
#define MQTT_PASSWORD           ""
// Over-The-Air Update password if used
#define OTA_PASSWORD            "password"
*/

/******************************************************************
 * Defines and enumerations
 ******************************************************************/
// time in milliseconds that a WiFi connection is unresponsive before reconnecting
#define         WIFI_CONNECTION_RETRY_TIME    15*60*1000
// time in milliseconds between MQTT connection attempts
#define         MQTT_CONNECTION_DELAY_TIME    10*1000
// Enumeration for pump state
enum PumpStateEnum {PS_RESET, PS_TANK_EMPTY, PS_OVERTEMP, PS_OFF, PS_OFF_A, PS_MANUAL_ON, PS_MANUAL_ON_A, PS_AUTO_ON, PS_OVER_ON}; 
// Enumeration for alarm state
enum AlarmStateEnum {AS_RESET, AS_OFF, AS_OVERTEMP, AS_TANK_HIGH, AS_AIR_PUMP, AS_BLEACH_LEVEL};
// pin number array for the eight inputs on this board (pins are D7, MISO, D1, D4, SCK, MOSI)
const uint8_t input_pins[NUMBER_INPUTS] = {7, 10, 1, 4, 9, 8};

/******************************************************************
 * Global Variables
 ******************************************************************/
// network
WiFiClient     net;
// MQTT CLient
MQTTClient     mqtt(1024);
// current input state, arranged in array by input_pins
int8_t         inputState[NUMBER_INPUTS] = {-1, -1, -1, -1, -1, -1};
// when true a hardware reset just occurred
bool           resetOccurred = true;
// when true WiFi was recently disconnected from the network
bool           wifiDisconnectOccurred = true;
// when true WiFi was recently connected to the network
bool           wifiConnectOccurred = false;
// current state for Pump State machine
PumpStateEnum  curPumpState = PS_RESET;
// last state for Pump State machine
PumpStateEnum  lastPumpState = PS_RESET;
// current state for alarm state machine
AlarmStateEnum curAlarmState = AS_RESET;
// last state for Alarm State machine
AlarmStateEnum lastAlarmState = AS_RESET;

/******************************************************************
 * Reset the watchdog timer
 ******************************************************************/
inline void watchdogReset(void) {
  #ifdef ENABLE_WATCHDOG
  if (!WDT->STATUS.bit.SYNCBUSY)                // Check if the WDT registers are synchronized
    REG_WDT_CLEAR = WDT_CLEAR_CLEAR_KEY;        // Clear the watchdog timer
  #endif
}

/******************************************************************
 * Is Alarm On?
 ******************************************************************/
bool isAlarmOn() {
  return curAlarmState == AS_TANK_HIGH ||
         curAlarmState == AS_AIR_PUMP ||
         curAlarmState == AS_BLEACH_LEVEL;
}

/******************************************************************
 * Is Pump On?
 ******************************************************************/
bool isPumpOn() {
  return curPumpState == PS_MANUAL_ON ||
         curPumpState == PS_MANUAL_ON_A ||
         curPumpState == PS_AUTO_ON ||
         curPumpState == PS_OVER_ON;
}

/******************************************************************
 * Display Pump State on LCD
 * 
 * force - Force Display Update
 *   When true forces a display update even on states normally 
 *   ignored.
 ******************************************************************/
void displayPumpState(bool force) {
  // display current pump state
  switch (curPumpState) {
    case PS_TANK_EMPTY:
      Logln("Entered PS_TANK_EMPTY State.");
      if (!isAlarmOn()) {
        SepticLCD.setDisplayMessage("Tank Empty");
      }
      break;
    case PS_OVERTEMP:
      Logln("Entered PS_OVERTEMP State.");
      // AS_OVERTEMP is entered at the same time so alarm will always 
      // take presidence, so no need to display this state on LCD
      break;
    case PS_OFF:
      Logln("Entered PS_OFF State.");
      if (!isAlarmOn()) {
        SepticLCD.setDisplayMessage("Idle");
      }
      break;
    case PS_OFF_A:
      Logln("Entered PS_OFF_A State.");
      if (!isAlarmOn() && force) {
        SepticLCD.setDisplayMessage("Idle");
      }
      break;
    case PS_MANUAL_ON:
      Logln("Entered PS_MANUAL_ON State.");
      if (!isAlarmOn()) {
        SepticLCD.setDisplayMessage("Manual Pump On");
      }
      break;
    case PS_MANUAL_ON_A:
      Logln("Entered PS_MANUAL_ON_A State.");
      if (!isAlarmOn() && force) {
        SepticLCD.setDisplayMessage("Manual Pump On");
      }
      break;
    case PS_AUTO_ON:
      Logln("Entered PS_AUTO_ON State.");
      if (!isAlarmOn()) {
        SepticLCD.setDisplayMessage("Auto Pump On");
      }
      break;
    case PS_OVER_ON:
      Logln("Entered PS_OVER_ON State.");
      if (!isAlarmOn()) {
        SepticLCD.setDisplayMessage("Override Pump On");
      }
      break;
    default:
      break;
  }
}

/******************************************************************
 * Verify/Make WiFi and MQTT connections
 ******************************************************************/
bool connect() {
  static uint8_t  lastMQTTRetryCount = 0;
  static uint32_t lastMQTTRetryTime = millis() - 10*1000;
  static uint32_t lastDisconnectTime;
  byte            mac[6];
  IPAddress       ip;
  int32_t         status = WiFi.status();

  // Reset the watchdog every time connect() is called
  watchdogReset();
  
  if (status != WL_CONNECTED) {
    // Wifi is disconnected
    wifiDisconnectOccurred = true;                    // we were disconnected
    if (abs(millis() - lastDisconnectTime) > 4*WIFI_CONNECTION_RETRY_TIME) {
      // something went wrong with lastDisconnectTime, reset
      lastDisconnectTime = millis() - WIFI_CONNECTION_RETRY_TIME - 10;
    }
    if (millis() - lastDisconnectTime > WIFI_CONNECTION_RETRY_TIME) {
      // it's been too long since we were last connected, turn off WiFi module
      WiFi.end();
      // turn on WINC1500 WiFi module and connect to network again
      WiFi.begin(SECRET_SSID, SECRET_PASSWORD);
      // try reconnecting after another full timeout
      lastDisconnectTime = millis();
      Println("Reconnecting to SSID: " SECRET_SSID "...");
    }
    return false;                                     // return with not connected
  }
  
  // update last time we were disconnected to now because WiFi is connected
  lastDisconnectTime = millis();
  
  if (wifiDisconnectOccurred && (status == WL_CONNECTED)) {
    // WiFi just connected
    Println("Connected to SSID: " SECRET_SSID);
    
    // we have detected that we just connected
    wifiDisconnectOccurred = false;                   // so we won't print network stats until next reconnect
    wifiConnectOccurred = true;                       // so MQTT publishing will know that Wifi just connected
    
    // enable WiFi Low Power Mode
    #ifdef ENABLE_WIFI_LOW_POWER
    WiFi.lowPowerMode();
    Println("  Low Power Mode enabled");
    #endif
    
    #ifdef ENABLE_SERIAL
    // display MAC Address
    WiFi.macAddress(mac);
    Print("  MAC Address: ");
    for (int i = 5; i != 0; i--) {
      if (mac[i] < 16) Print("0");
      Print(mac[i], HEX);
      Print(":");
    }
    if (mac[0] < 16) Print("0");
    Println(mac[0], HEX);
    
    // Display IP Address
    ip = WiFi.localIP();
    Print("  IP Address: ");
    Println(ip);
    #endif
    
    #ifdef ENABLE_OTA_UPDATES
    // start the WiFi OTA library with internal based storage
    WiFiOTA.begin(BOARD_NAME, OTA_PASSWORD, InternalStorage);
    Println("WiFi OTA updates enabled");
    #endif
  
    // start the WiFi Real Time Clock
    WiFiRTC.begin(TZDIFF, NTP_SERVER);
  }
  
  if (!mqtt.connected()) {
    if (++lastMQTTRetryCount >= WIFI_CONNECTION_RETRY_TIME/MQTT_CONNECTION_DELAY_TIME) {
      // it's been too long since we had an MQTT connection, turn off WiFi module
      WiFi.end(); 
      // turn on WINC1500 WiFi module and connect to network again
      WiFi.begin(SECRET_SSID, SECRET_PASSWORD);
      lastMQTTRetryTime = millis();                   // restart MQTT retry time
      lastMQTTRetryCount = 0;                         // MQTT retry count will need to start over
      return false;                                   // we are not connected
    }
    if (abs(millis() - lastMQTTRetryTime) > 4*MQTT_CONNECTION_DELAY_TIME) {
      // something went wrong with lastMQTTRetryTime, reset
      lastMQTTRetryTime = millis() - MQTT_CONNECTION_DELAY_TIME - 1;
    }
    // we are not currently connected to MQTT Server
    if (millis() - lastMQTTRetryTime <= MQTT_CONNECTION_DELAY_TIME) {
      // not time to retry MQTT connection
      return false;
    }
    // time to retry server connection
    Log("Connecting to MQTT Server:" MQTT_SERVER "...");
    if (mqtt.connect(BOARD_NAME, MQTT_USERNAME, MQTT_PASSWORD)) {
      // successfully connected to MQTT server
      Println("Success");
    } else {
      // failed to connect to MQTT server
      Println("Failed");
      ++lastMQTTRetryCount;
      lastMQTTRetryTime = millis();
      return false;
    }
    
    // set Home Assistant Availibility Topic to available
    if (!mqtt.publish(HASS_AVAIL_TOPIC, HASS_PAYLOAD_AVAIL, true, 1)) {
      Logln("Failed to publish '" HASS_AVAIL_TOPIC "' MQTT topic");
    } else {
      Logln("Published '" HASS_AVAIL_TOPIC "' MQTT topic, '" HASS_PAYLOAD_AVAIL "' topic value");
    }
    
    // publish Home Assistant temperature config Topic
    if (!mqtt.publish(HASS_TEMP_CONFIG_TOPIC, HASS_TEMP_CONFIG, true, 1)) {
      Logln("Failed to publish '" HASS_TEMP_CONFIG_TOPIC "' MQTT topic");
    } else {
      Logln("Published '" HASS_TEMP_CONFIG_TOPIC "' MQTT topic, '" HASS_TEMP_CONFIG "' topic value");
    }
    
    // publish Home Assistant RSSI config topic
    if (!mqtt.publish(HASS_RSSI_CONFIG_TOPIC, HASS_RSSI_CONFIG, true, 1)) {
      Logln("Failed to publish '" HASS_RSSI_CONFIG_TOPIC "' MQTT topic");
    } else {
      Logln("Published '" HASS_RSSI_CONFIG_TOPIC "' MQTT topic, '" HASS_RSSI_CONFIG "' topic value");
    }
    
    // publish Home Assistant pump config topic
    if (!mqtt.publish(HASS_PUMP_CONFIG_TOPIC, HASS_PUMP_CONFIG, true, 1)) {
      Logln("Failed to publish '" HASS_PUMP_CONFIG_TOPIC "' MQTT topic");
    } else {
      Logln("Published '" HASS_PUMP_CONFIG_TOPIC "' MQTT topic, '" HASS_PUMP_CONFIG "' topic value");
    }
    
    // publish Home Assistant alarm config topic
    if (!mqtt.publish(HASS_ALARM_CONFIG_TOPIC, HASS_ALARM_CONFIG, true, 1)) {
      Logln("Failed to publish '" HASS_ALARM_CONFIG_TOPIC "' MQTT topic");
    } else {
      Logln("Published '" HASS_ALARM_CONFIG_TOPIC "' MQTT topic, '" HASS_ALARM_CONFIG "' topic value");
    }
    
    // publish Home Assistant pump status config topic
    if (!mqtt.publish(HASS_STATUS_CONFIG_TOPIC, HASS_STATUS_CONFIG, true, 1)) {
      Logln("Failed to publish '" HASS_STATUS_CONFIG_TOPIC "' MQTT topic");
    } else {
      Logln("Published '" HASS_STATUS_CONFIG_TOPIC "' MQTT topic, '" HASS_STATUS_CONFIG "' topic value");
    }
    
    if (resetOccurred) {                              // Hardware reset occurred
      // reset just recently occurred
      if (!mqtt.publish(HASS_STATUS_STATE_TOPIC, "Reset Hardware", true, 1)) {
        Logln("Failed to publish '" HASS_STATUS_STATE_TOPIC "' MQTT topic, 'Reset Hardware' topic value");
      } else {
        Logln("Published '" HASS_STATUS_STATE_TOPIC "' MQTT topic, 'Reset Hardware' topic value");
      }
    } else if (wifiConnectOccurred) {                 // WiFi Connected
      // Wifi just connected
      if (!mqtt.publish(HASS_STATUS_STATE_TOPIC, "Reset WiFi Connect", true, 1)) {
        Logln("Failed to publish '" HASS_STATUS_STATE_TOPIC "' MQTT topic, 'Reset WiFi Connect' topic value");
      } else {
        Logln("Published '" HASS_STATUS_STATE_TOPIC "' MQTT topic, 'Reset WiFi Connect' topic value");
      }
/*    } else {
      // MQTT just connected
      if (!mqtt.publish(HASS_STATUS_STATE_TOPIC, "Reset MQTT Connect", true, 1)) {
        // since no reset or WiFi connect occurred then it was a MQTT Connect
        Logln("Failed to publish '" HASS_STATUS_STATE_TOPIC "' MQTT topic, 'ResetMQTT Connect' topic value");
      } else {
        Logln("Published '" HASS_STATUS_STATE_TOPIC "' MQTT topic, 'Reset MQTT Connect' topic value");
      }*/
    }
    
    // Home Assistant will ignore too frequent publishing on topics
    // Specifically we want HASS_STATUS_STATE_TOPIC to show the Reset events above and the soon to come Idle
    delay(1000);
    
    // clear the connect reason flags
    resetOccurred = false;
    wifiConnectOccurred = false;
    
    // we had to reconnect to MQTT Broker make sure at least one false is returned
    return false;
  }
  
  // be ready for next MQTT retry time
  lastMQTTRetryTime = millis();
  lastMQTTRetryCount = 0;
  
  // if we got here then we are connected
  return true;
}
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
void loop() {
  static uint32_t nextTempPublish = 0;                // used to publish the temp at a defined rate
  static uint32_t lastDebounceTime[NUMBER_INPUTS] = {0, 0, 0, 0, 0, 0};
  static int8_t   lastDebounceInput[NUMBER_INPUTS] = {-1, -1, -1, -1, -1, -1};
  static uint32_t lastPSDeadbandTime;                 // add a deadband between pump state changes
  static uint32_t lastASDeadbandTime;                 // add a deadband between alarm state changes
  static uint8_t  lastEffluentPumpSense = -1;         // last sensed effuent pump state
  static uint32_t lastPumpOnStartTime = 0;                 // last pump on time was now
  static uint32_t lastPumpOffStartTime = 0 - 4*60*60*1000; // last pump off start time (default is 4 hours ago)
  static bool     publishPumpState = true;            // when true pump status should be published to MQTT server
  static bool     publishAlarmState = true;           // when true alarm status should be published to MQTT server
  static bool     publishSepticStatus = true;         // when true septic status should be published to MQTT server
  PumpStateEnum   nextPumpState = curPumpState;       // next state for pump state machine, default is no change
  AlarmStateEnum  nextAlarmState = curAlarmState;     // next state for alarm state machine, default is no change
  uint32_t        timeDiff;                           // how long has it been since pump was last on
  float           temperature;                        // temperature reading
  char            tempStr[16];                        // temporary string
  uint8_t         inputReading;                       // last input read
  bool            inputStabilized = true;             // when true inputs are stabilized and are ready to be read
  
  // keep track of time appropriately
  WiFiRTC.loop();
  
  #ifdef ENABLE_OTA_UPDATES
  // check for WiFi OTA updates
  WiFiOTA.poll();
  #endif

  // MQTT client loop call
  mqtt.loop();
  
  // debounce input
  for (int i = 0; i < NUMBER_INPUTS; i++) {
    // get current input debounce time
    // read the current input state
    inputReading = digitalRead(input_pins[i]);
    // update last debounce time if the state has changed
    if (inputReading != lastDebounceInput[i]) {
      // reset the debounce timer
      lastDebounceTime[i] = millis();
    }
    uint32_t debounceTime = millis() - lastDebounceTime[i];
    // if debounce time has elapsed then the input is stable
    if (debounceTime > DEBOUNCE_TIME) {
      // debounce finished 
      if (i == PUMP_TOGGLE_SWITCH) {
        // were are working the pump toggle input and rising edge
        if (debounceTime > PUMP_TOGGLE_DEBOUNCE_TIME) {
          // debounce was long enough
          inputState[i] = inputReading;               // update input state
        }
      } else if (i == FLOAT_ALARM ||
                 i == AIR_ALARM ||
                 i == BLEACH_ALARM) {
        // were are working alarm input
        if (debounceTime > ALARM_DEBOUNCE_TIME) {
          // debounce was long enough
          inputState[i] = inputReading;               // update input state
        }
      } else {
        // we are working on a normal input
        inputState[i] = inputReading;                 // update input state
      }
    }
    // prevent debounce time from getting too big
    if (debounceTime > 60 * 60 * 1000) {
      lastDebounceTime[i] = millis() - 60 * 1000;
    }
    // last reading is now current
    lastDebounceInput[i] = inputReading;
  }

  // inputs must have stabilized before they are read for the first time
  for(int i = 0; i < NUMBER_INPUTS; i++) {
    // check input to see if it is still default
    if (inputState[i] == -1) {
      inputStabilized = false;
      break;
    }
  }
  
  // handle LCD background color
  if (curAlarmState != AS_OFF) {
    // alarm is on
    SepticLCD.setBacklightColor(COLOR_ALARM);
  } else if (inputState[EFFLUENT_PUMP_SENSE] == SENSE_ACTIVE) {
    // pump is on
    SepticLCD.setBacklightColor(COLOR_PUMPING);
  } else {
    // idle
    SepticLCD.setBacklightColor(COLOR_IDLE);
  }

  // get the most recent temperature
  temperature = SepticLCD.getTemperatureC();

  // if inputs are stabilized then check inputs as normal
  if (inputStabilized) {
    // handle Alarm State changing states
    if (lastAlarmState != curAlarmState) {
      switch (curAlarmState) {
        case AS_OFF:
          // just entered Alarm Off state
          Logln("Entered AS_OFF State.");
          displayPumpState(true);
          digitalWrite(ALARM_LED, LOW);
          break;
        case AS_OVERTEMP:
          // just entered Overtemp Alarm state
          Logln("Entered AS_OVERTEMP State.");
          SepticLCD.setDisplayMessage("Overtemp Alarm");
          digitalWrite(ALARM_LED, HIGH);
          break;
        case AS_TANK_HIGH:
          // just entered Float Alarm state
          Logln("Entered AS_TANK_HIGH State.");
          SepticLCD.setDisplayMessage("Tank High Alarm");
          digitalWrite(ALARM_LED, HIGH);
          break;
        case AS_AIR_PUMP:
          // just entered Air Pump Alarm state
          Logln("Entered AS_AIR_PUMP State.");
          SepticLCD.setDisplayMessage("Air Pump Alarm");
          digitalWrite(ALARM_LED, HIGH);
          break;
        case AS_BLEACH_LEVEL:
          // just entered Bleach Alarm state
          Logln("Entered AS_BLEACH_LEVEL State.");
          SepticLCD.setDisplayMessage("Bleach Alarm");
          digitalWrite(ALARM_LED, HIGH);
          break;
      }
    
      // Alarm State changed so time to publish
      publishSepticStatus = true;
      publishAlarmState = true;

      // last Alarm State is now current Alarm State
      lastAlarmState = curAlarmState;
    }
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

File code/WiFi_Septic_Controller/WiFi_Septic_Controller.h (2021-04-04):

/*
  WiFi Septic Controller Project wide defines

  Copyright (c) 2021 Mike Lawrence

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
  THE SOFTWARE IS PROVIDED "AS IS", WITHOUT WARRANTY OF ANY KIND, EXPRESS OR
  IMPLIED, INCLUDING BUT NOT LIMITED TO THE WARRANTIES OF MERCHANTABILITY,
  FITNESS FOR A PARTICULAR PURPOSE AND NONINFRINGEMENT. IN NO EVENT SHALL THE
  AUTHORS OR COPYRIGHT HOLDERS BE LIABLE FOR ANY CLAIM, DAMAGES OR OTHER
  LIABILITY, WHETHER IN AN ACTION OF CONTRACT, TORT OR OTHERWISE, ARISING FROM,
  OUT OF OR IN CONNECTION WITH THE SOFTWARE OR THE USE OR OTHER DEALINGS IN THE
  SOFTWARE.
*/

#ifndef WIFI_SEPTIC_CONTROLLER_H
#define WIFI_SEPTIC_CONTROLLER_H

/******************************************************************
 * Build defines
 ******************************************************************/
// Enable Watchdog Timer
#define ENABLE_WATCHDOG
// Enable OTA updates
#define ENABLE_OTA_UPDATES
// Enable Serial on USB
#define ENABLE_SERIAL
// Enable Low Power Mode on WiFi
//#define ENABLE_WIFI_LOW_POWER
// Current Version
#define VERSION                   "0.6"

/******************************************************************
 * Application defines
 ******************************************************************/
// Name of this board, each board should be unique
// Used as MQTT Client ID, HASS Name, and OTA Name
#define BOARD_NAME                "Septic"
// input debounce time in milliseconds
#define DEBOUNCE_TIME             100
// pump toggle switch input debounce time in milliseconds
//   Should be larger than DEBOUNCE_TIME
#define PUMP_TOGGLE_DEBOUNCE_TIME 500
// pump toggle switch input debounce time in milliseconds
//   Should be larger than DEBOUNCE_TIME
#define ALARM_DEBOUNCE_TIME       1000
// pump state machine deadband time in milliseconds
#define PUMP_DEADBAND_TIME        2000
// alarm state machine deadband time in milliseconds
#define ALARM_DEADBAND_TIME       2000
// temperature publish time in milliseconds when pump is off
#define TEMP_PUBLISH_RATE         1*60*1000
// NTP server used to update local time, can be IP Address or name
#define NTP_SERVER                "time.nist.gov"
// timezone difference from GMT in hours (Standard Time difference)
#define TZDIFF                    -6
// Solid State Relay shutoff temperature in Celsius
#define SSR_SHUTOFF_TEMP          65.0

/******************************************************************
 * Home Assistant MQTT Defines
 ******************************************************************/
#define HASS_PREFIX               "homeassistant"
#define HASS_NODE_NAME            "septic"

// HASS defines below here should not be modified
#define HASS_AVAIL_TOPIC          HASS_PREFIX "/sensor/" HASS_NODE_NAME "/avail"
#define HASS_PAYLOAD_AVAIL        "online"
#define HASS_PAYLOAD_NOT_AVAIL    "offline"

#define HASS_TEMP_CONFIG_TOPIC    HASS_PREFIX "/sensor/" HASS_NODE_NAME "/temperature/config"
#define HASS_TEMP_STATE_TOPIC     HASS_PREFIX "/sensor/" HASS_NODE_NAME "/temperature/state"
#define HASS_TEMP_CONFIG          "{ \"name\": \"" BOARD_NAME " Temperature\", \"stat_t\": \"" HASS_TEMP_STATE_TOPIC \
                                  "\", \"unit_of_meas\": \"°C\", \"avty_t\": \"" HASS_AVAIL_TOPIC "\" }"
                                  
#define HASS_RSSI_CONFIG_TOPIC    HASS_PREFIX "/sensor/" HASS_NODE_NAME "/rssi/config"
#define HASS_RSSI_STATE_TOPIC     HASS_PREFIX "/sensor/" HASS_NODE_NAME "/rssi/state"
#define HASS_RSSI_CONFIG          "{ \"name\": \"" BOARD_NAME " RSSI\", \"stat_t\": \"" HASS_RSSI_STATE_TOPIC \
                                  "\", \"unit_of_meas\": \"dBm\", \"avty_t\": \"" HASS_AVAIL_TOPIC "\" }"
                                  
#define HASS_PUMP_CONFIG_TOPIC    HASS_PREFIX "/binary_sensor/" HASS_NODE_NAME "/pump/config"
#define HASS_PUMP_STATE_TOPIC     HASS_PREFIX "/binary_sensor/" HASS_NODE_NAME "/pump/state"
#define HASS_PUMP_CONFIG          "{ \"name\": \"" BOARD_NAME " Pump\", \"stat_t\": \"" HASS_PUMP_STATE_TOPIC \
                                  "\", \"avty_t\": \"" HASS_AVAIL_TOPIC "\" }"

#define HASS_ALARM_CONFIG_TOPIC   HASS_PREFIX "/binary_sensor/" HASS_NODE_NAME "/alarm/config"
#define HASS_ALARM_STATE_TOPIC    HASS_PREFIX "/binary_sensor/" HASS_NODE_NAME "/alarm/state"
#define HASS_ALARM_CONFIG         "{ \"name\": \"" BOARD_NAME " Alarm\", \"stat_t\": \"" HASS_ALARM_STATE_TOPIC \
                                  "\", \"dev_cla\": \"problem\", \"avty_t\": \"" HASS_AVAIL_TOPIC "\" }"

#define HASS_STATUS_CONFIG_TOPIC  HASS_PREFIX "/sensor/" HASS_NODE_NAME "/status/config"
#define HASS_STATUS_STATE_TOPIC   HASS_PREFIX "/sensor/" HASS_NODE_NAME "/status/state"
#define HASS_STATUS_CONFIG        "{ \"name\": \"" BOARD_NAME " Status\", \"stat_t\": \"" HASS_STATUS_STATE_TOPIC \
                                  "\", \"avty_t\": \"" HASS_AVAIL_TOPIC "\" }"

/******************************************************************
 * Board Defines
 ******************************************************************/
// Output pin defines
#define EFFLUENT_PUMP_RELAY       0
#define LCD_RS                    PIN_A1
#define LCD_E                     PIN_A2
#define LCD_D4                    PIN_A0
#define LCD_D5                    25
#define LCD_D6                    PIN_A5
#define LCD_D7                    PIN_A6
#define LCD_BACKLIGHT_R           PIN_A3
#define LCD_BACKLIGHT_G           PIN_A4
#define LCD_BACKLIGHT_B           11
// Output State defines
#define PUMP_RELAY_ACTIVE         HIGH
#define PUMP_RELAY_INACTIVE       LOW
// Input array defines
#define NUMBER_INPUTS             6
#define EFFLUENT_PUMP_SENSE       0
#define SPARE_SENSE               1
#define FLOAT_ALARM               2
#define AIR_ALARM                 3
#define BLEACH_ALARM              4
#define PUMP_TOGGLE_SWITCH        5
// Input State defines
#define SENSE_ACTIVE              LOW
#define SENSE_INACTIVE            HIGH
#define ALARM_ACTIVE              HIGH
#define ALARM_INACTIVE            LOW
#define PUMP_TOGGLE_ACTIVE        HIGH
#define PUMP_TOGGLE_INACTIVE      LOW
// LED
#define BOARD_LED                 6
#define ALARM_LED                 BOARD_LED
// 1-Wire pin
#define OWIRE                     2

// Logging/Printing defines
#ifdef ENABLE_SERIAL
#define Print(...)                Serial.print(__VA_ARGS__)
#define Println(...)              Serial.println(__VA_ARGS__)
#define Log(...)                  {WiFiRTC.printTimeHMS24Hr();Serial.print(' ');Serial.print(__VA_ARGS__);}
#define Logln(...)                {WiFiRTC.printTimeHMS24Hr();Serial.print(' ');Serial.println(__VA_ARGS__);}
#else
#define Print(...)
#define Println(...)
#define Log(...)
#define Logln(...)
#endif

#endif // WIFI_SEPTIC_CONTROLLER_H

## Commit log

2018-05-14 Initial commit. Board sent out for fab. No code yet.
    [WiFi-Septic-Controller-BOM.csv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]
2018-05-14 Update 3D board preview.
2018-05-14 Update 3D board view again.
2018-05-14 Changed ALM label on schematic to match PCB silkscreen.
    [WiFi-Septic-Controller.sch]
2018-05-17 Updated 3D Model. Minor README corrections.
    [WiFi-Septic-Controller.kicad_pcb]
2018-05-21 Changed transformer part number. Alarm Labels on schematic now match PCB positions. Update PCB Status.
    [WiFi-Septic-Controller-BOM.csv, WiFi-Septic-Controller.sch]
2018-05-21 Added wiring diagram.
2018-05-22 First commit of the Arduino Sketch.
2018-05-27 First operational version. Software now working in actual system.
    First operation software version. Added Septic Wiring Diagram (use draw.io). Added Arduino's RCTZero directly to project to add getTime() which greatly improves time read perfomance.
2018-05-31 Upped Version to 0.2. Added over temperature for SSR. Watchdog Timeout changed.
    Solid State Relay will now be disabled when temperature exceeds 65C. Temperature no longer has a faster publish rate when the pump is on, instead Temperature and RSSI publish every minute. Watchdog Timeout set to 64 seconds from 16 seconds. MQTT keepalive interval changed to 65 seconds from 15 minutes. Reorganized code.
    [WiFi_Septic_Controller.h, WiFi_Septic_Controller.ino]
2018-06-03 Disabled "Reset MQTT Connect" status. Fixed temperature publishing catchup.
    Status no longer sends a "Reset MQTT Connect" status. Fixed temperature publishing to prevent a series of catchup publishes if the MQTT server was offline for a while.
    [WiFi_Septic_Controller.ino]
2018-06-11 Upped version to 0.3. Improved WiFi reliablity, add NTP handling.
    Sometime WIFi looses access to network without showing disconnected in status. To get around this timeout on MQTT connect retries was added. This stops the WiFi connection so it can reconnect. The ATWINC1500 module apparently does not keep good time so NTP was added to the Real-Time Clock section. Time keeping is now significantly better at room temperature. Removed pump on too long timeout in PS_AUTO_ON state.
    [WiFiRTC.ino, WiFi_Septic_Controller.h, WiFi_Septic_Controller.ino]
2018-06-11 Fix time not updating properly.
    [WiFiRTC.ino, WiFi_Septic_Controller.h, WiFi_Septic_Controller.ino]
2018-06-12 Added automatic support for testing on other boards.
    Minor corrections in README.
    [WiFi_Septic_Controller.ino]
2018-07-05 Increase alarm input debounce time.
    Occasionally seeing High Float Alarms around the time the pump turns off.
2018-07-08 Change alarm input resistors
    The 100k alarm input resistors may be a high enough impedance to allow noise to trigger the over full alarm. Changed the resistors to 22k. Minor update to README file.
    [WiFi-Septic-Controller-BOM.csv, WiFi-Septic-Controller.sch]
2018-07-23 Update to KiCad 5.0.0. Remove unecessary files.
2018-08-21 Update Status in README.
    Also updated KiCad libraries.
2019-03-03 Arduino IDE 1.8.8,updated WINC1500 firmware to 19.6.1, updated MQTT to 2.4.1.
2019-03-12 Fix Watchdog Timer reset when NTP server fails to respond.
    Doubled the Watchdog timer reset period to 128 seconds to prevent reset when NTP server takes too long to respond on power cycle. Small cleanup to comments and commented code.
    [WiFiRTC.ino, WiFi_Septic_Controller.h, WiFi_Septic_Controller.ino]
2019-05-05 Update to KiCad 5.1 libraries.
    Also updated custom libraries.
    [WiFi-Septic-Controller-BOM.csv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]
2019-05-11 Remove unnecessary gerbers. Update gerber generation settings.
    [WiFi-Septic-Controller-B_Cu.gbl, WiFi-Septic-Controller-B_Mask.gbs, WiFi-Septic-Controller-B_Paste.gbp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]
2019-05-16 Cleanup BOM. VCC now +3V3.
    Add KiBoM support.
    Cleanup part information in schematic.
    Added power pins to schematic on multi-unit gates.
    [WiFi-Septic-Controller-BOM.csv, WiFi-Septic-Controller.kicad_pcb, WiFi-Septic-Controller.sch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]
2019-05-21 Arduino library updates.
2019-06-05 Minor formatting cleanup.
    [WiFi-Septic-Controller-BOM.csv]
2019-07-02 Add "device_class" to Alarm Config.
2019-12-09 Update library and Arduino IDE version.
2021-03-28 Add Home Assistant device support
    This will now show up as a device under mqtt integration. All entities will be associated with the device. Unique_id comes from SAMD21 processor serial.
2021-04-04 Revert to more stable code
    Recent changes to add Home Assistant device information to the MQTT topics caused instability. This is probably related to String library usage. The changes that caused problems are now in the device branch. Master is back to previous stability but without device support.
    [WiFi_Septic_Controller.h, WiFi_Septic_Controller.ino]
2021-04-04 Change MQTT options
    Switch NTP server to time.nist.gov
2021-11-08 Update Kicad link.
